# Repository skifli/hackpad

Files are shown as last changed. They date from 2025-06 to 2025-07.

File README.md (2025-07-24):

# hackpad

- [hackpad](#hackpad)
  - [Project Structure](#project-structure)
  - [Journal](#journal)
  - [PCB](#pcb)
    - [Schematic](#schematic)
    - [PCB Design](#pcb-design)
    - [PCB Render](#pcb-render)
  - [CAD](#cad)
  - [BOM](#bom)
  - [Software](#software)

| Cover | Exploded View |
| --- | --- |
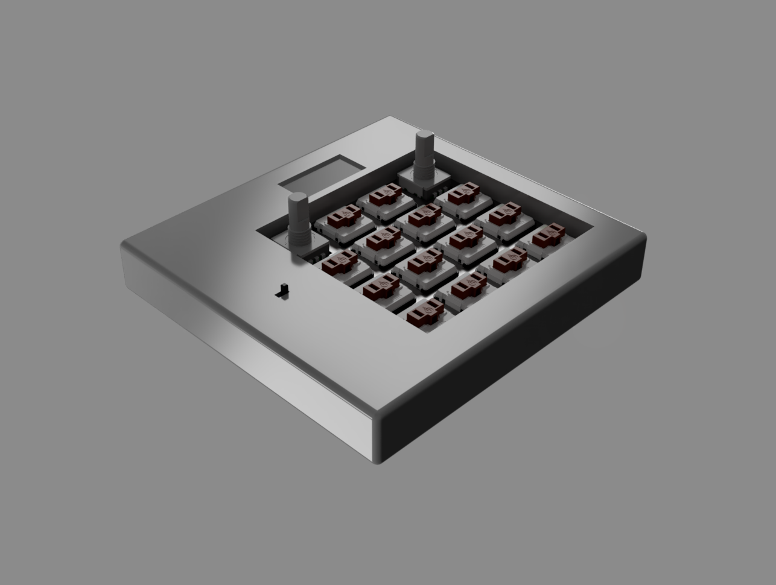
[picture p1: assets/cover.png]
cover photo
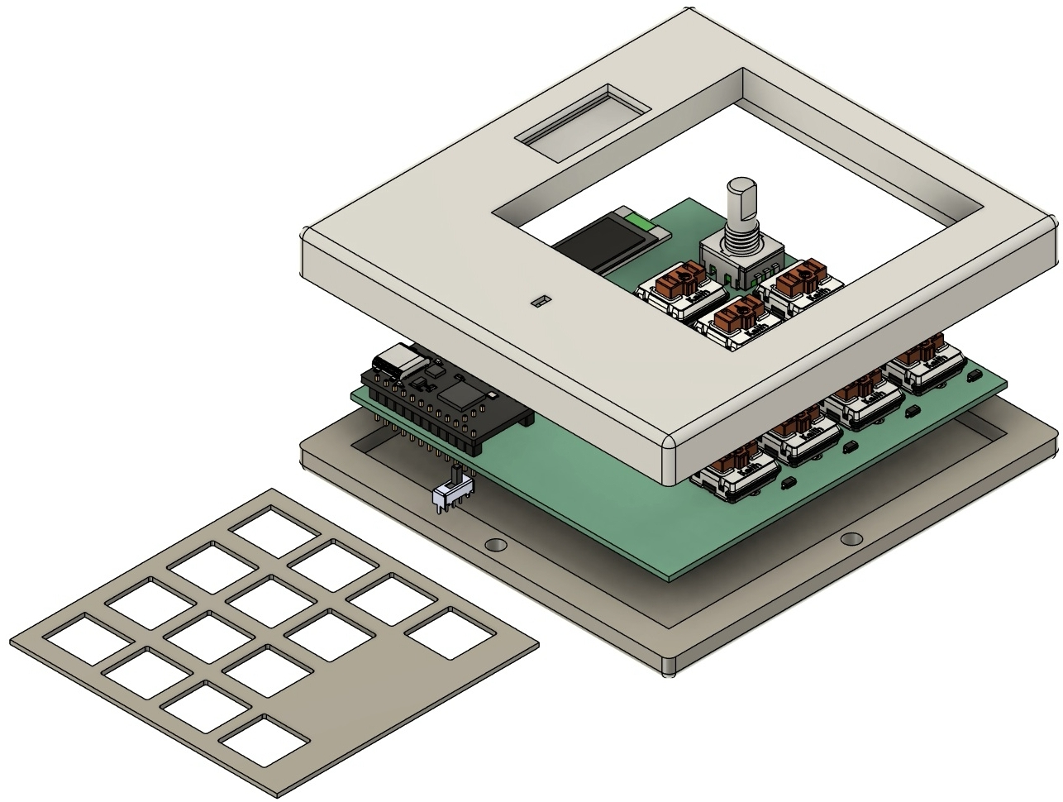
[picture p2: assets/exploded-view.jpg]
exploded view photo
|  |  |

> [!IMPORTANT]\
> Since submission, the BOM price has decreased to $119.89 from above $150 (check [#bom](#bom) for more information).

A fully wireless macropad with 14 Choc v1 Ambient Nocturnal switches, 2 rotary encoders (with a push-button each), and a small screen! The case is in two sections - a top and bottom, and joins together via 8 magnets, half in each side of the case (you can see the magnet holes in the various views).

I made this project because when programming / doing CAD design there are so many different shortcuts I use to make sketches, change orbit types, etc, and these require a lot of clicks. These all could be streamlined a lot more with the use of a macropad - which is why I made this one. I decided to also add a screen so I could easily see which profile I'm on and switch (likely by rotating a rotary encoder while it is held down), and the two rotary encoders to easily control multiple audio streams (mainly YouTube vs. Spotify).

## Project Structure

> [!IMPORTANT]\
> Only includes files / folders relevant to admin that would benefit from explanation.

```
└── 📁hackpad
    └── 📁design
        └── 📁cad
            ├── case_bottom.step
            ├── case_top.step
        └── 📁pcb
            ├── ... # Contains the KiCad directory for the PCB
        └── 📁plate
            ├── ... # Contains the KiCad directory for the plate, which is made from an exported DXF from the Fusion 360 Sketch (plate.dxf)
    ├── JOURNAL.md # The journal of the design process
    └── README.md # This file
```

> [!WARNING]\
> The KiCad plate PCB gives [malformed outline warnings](JOURNAL.md#20072025) and doesn't show correctly in 3D view - no idea why, but when exported with the Fabrication Toolkit and imported into JLCPCB it's totally fine 🗿 (if it works, it works™). 

## Journal

The [journal](JOURNAL.md) contains each day's work, logged, with the aid of images. Total time is at the top and each day has its time logged. There is also a Table of Contents for easy navigation :).

> [!NOTE]\
> Total time spent: **60h**

## PCB

### Schematic

kicad schematic

### PCB Design

kicad pcb design

### PCB Render

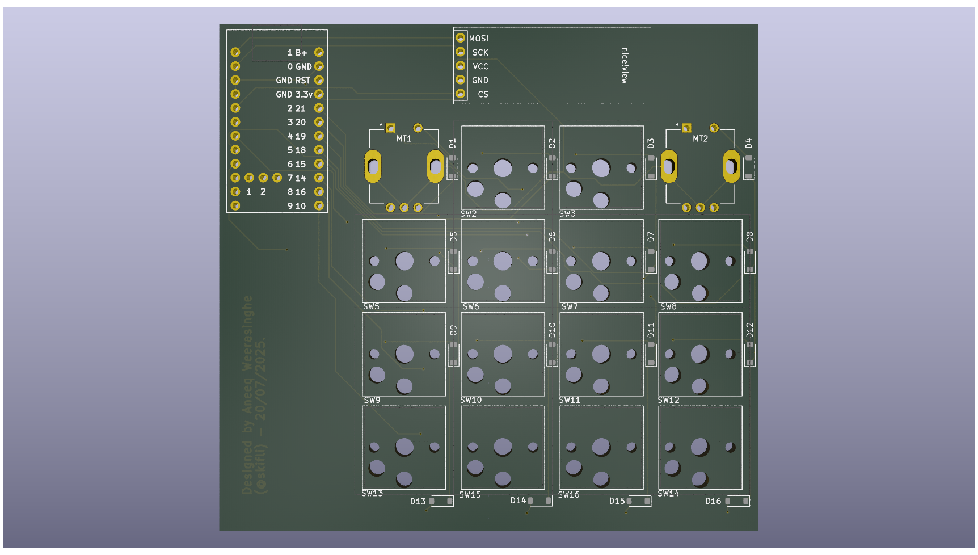
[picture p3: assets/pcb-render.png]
kicad pcb render


## CAD

| Case Top Side View (from the bottom) | Case Bottom Side View (from the top) |
| --- | --- |
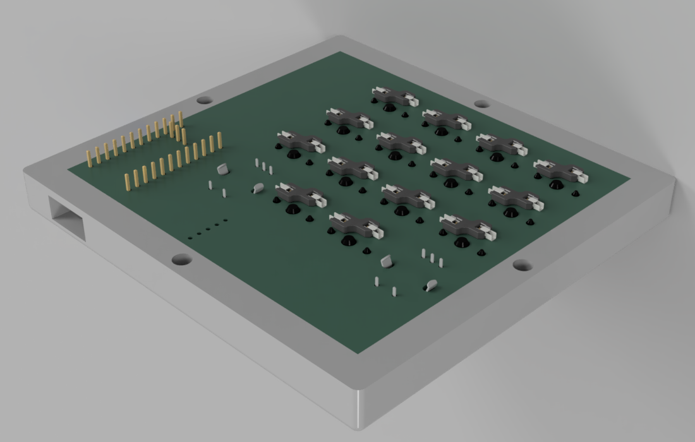
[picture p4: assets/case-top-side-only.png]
case top side only
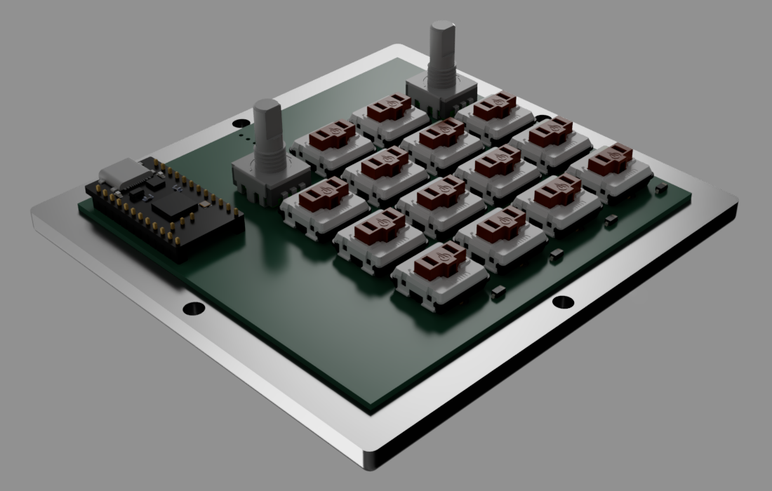
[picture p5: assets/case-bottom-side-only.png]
case bottom side only
|  |  |

| Case Plate | Case USB Port |
| --- | --- |
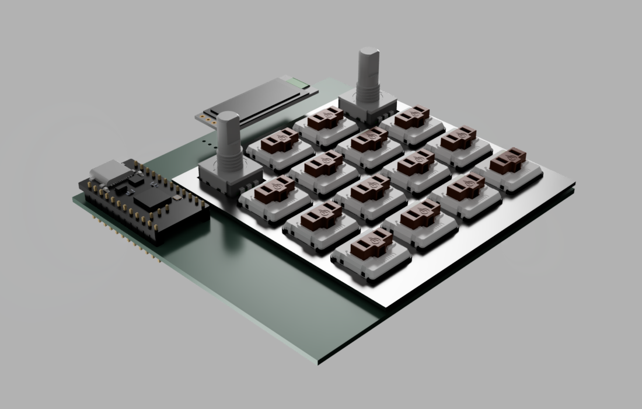
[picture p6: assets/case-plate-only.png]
case plate only
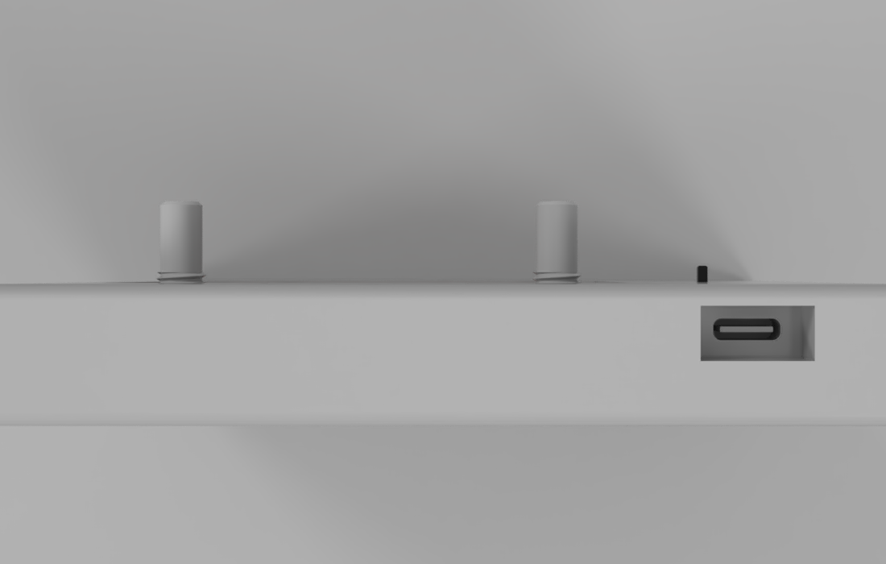
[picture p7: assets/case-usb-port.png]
case usb port
|  |  |

## BOM

> [!TIP]\
> The BOM is split into the different companies from which the components would be bought, with an empty line delimiting them. As well as this, at the end of each section, the total price for that provider, along with the shipping, is provided in the **Price** column. There is also the total price in the aforementioned column on the last row.

> [!NOTE]\
> I found the promo code **KBDNEWS** for Mechboards (a UK-based merchant) 5% off so I included that in the BOM as well to explain the decrease in total price.

<details closed>
<summary>BOM in table format</summary>

| Component | Description | Notes | Qty | Price | Shipping | Provider | Link |
| --- | --- | --- | --- | --- | --- | --- | --- |
| Kailh Choc Hotswap Sockets | V1 (Pack of 10) | | 2 | £6.00 | £1.81 | Mechboards | [Link](https://mechboards.co.uk/products/kailh-choc-hotswap-sockets?variant=40427263754445) |
| DDC Choc (v1) PBT Blank Keycaps - White | White Keycaps / 1u (Pack of 10) | | 1 | £4.50 | – | Mechboards | [Link](https://mechboards.co.uk/products/ddc-choc-pbt-blank-keycaps?variant=47587896426701) |
| DDC Choc (v1) PBT Blank Keycaps - Black | Black Keycaps / 1u (Pack of 10) | | 1 | £4.50 | – | Mechboards | [Link](https://mechboards.co.uk/products/ddc-choc-pbt-blank-keycaps?variant=47405364576461) |
| lowprokb Choc (V1) Ambients Nocturnal | (Pack of 10) | | 2 | £19.00 | – | Mechboards | [Link](https://mechboards.co.uk/products/lowprokb-ambients-silent-linear-nocturnal-choc-v1?variant=47588169908429) |
| KBDNEWS Promo Code | | | – | –£0.94 | – | – | – |
| **Total (Mechboards)** | | | | **£34.11** | *Included* | | |
| nice!nano v2 | | Compatible board | 1 | £2.99 | £2.99 | AliExpress | [Link](https://www.aliexpress.com/item/1005006035267231.html) |
| nice!view | | Compatible screen (without headers) | 1 | £12.69 | – | AliExpress | [Link](https://www.aliexpress.com/item/1005008115497843.html) |
| Header Pins | 1x5 Pins (50 PCS) | Headers for the above screen | 1 | £1.15 | – | AliExpress | [Link](https://www.aliexpress.com/item/4000988113226.html) |
| Tiny Disc Magnet | 4x3mm (100 PCS) | To join the top and bottom of the case | 1 | £4.86 | £2.96 | AliExpress | [Link](https://www.aliexpress.com/item/1005009177139622.html) |
| SMT SOD-123 Diodes | 100 PCS | For the switches | 1 | £1.11 | – | AliExpress | [Link](https://www.aliexpress.com/item/4000685043735.html) |
| Heat Shrink Tubes | | For wiring between switch, battery, nice!nano v2 | 1 | £1.35 | – | AliExpress | [Link](https://www.aliexpress.com/item/1005008146302901.html) |
| JST PH Plug Connector with Wire (M) | MALE 2P 100mm (5 PCS) | For battery wiring | 1 | £0.34 | £1.94 | AliExpress | [Link](https://www.aliexpress.com/item/1005008864177105.html) |
| JST PH Plug Connector with Wire (F) | FEMALE 2P 100mm (5 PCS) | For battery wiring | 1 | £0.49 | £1.94 | AliExpress | [Link](https://www.aliexpress.com/item/1005008864177105.html) |
| Bumper Feet | 5mm x 2mm (100 PCS) | For bottom of the case and PCB | 1 | £1.59 | – | AliExpress | [Link](https://www.aliexpress.com/item/1005004068119765.html) |
| Toggle Switch | K031b004-G3 | To power on/off the system | 1 | £1.94 | – | AliExpress | [Link](https://www.aliexpress.com/item/1005009306874094.html) |
| 3.7V 150mAh | 1 battery | To power the system | 1 | £4.74 | N/A | AliExpress | [Link](https://www.aliexpress.com/item/1005004084377638.html) |
| Rotary Encoder w/ Push Button | 5 PCS | | 1 | £1.08 | – | AliExpress | [Link](https://www.aliexpress.com/item/1005005983134515.html) |
| **Total (AliExpress)** | | | | **£42.35** | *Included* | | |
| Plate & PCB | | | | £5.94 | £6.11 | JLCPCB | N/A |
| **Total (JLCPCB)** | | | | **£12.05** | *Included* | | |
| **TOTAL** | | | | **£88.51** | *Included* | | |  |

</details>

> [!IMPORTANT]\
> Please disregard a lot of what is in the below text. After someone in the Slack (@Toby), introduced me to the world of AliExpress, I completely redid the BOM. It is now $119.89 (yes that is USD lol), so way under the limit. Thanks a lot dude :).

The BOM can be found in [`/bom.csv`](bom.csv). Since this is my first ever hardware project, I decided to go for some products that were easier to find footprints / symbols in KiCad for. With hindsight, spending the amount of money I now have to on a nice! nano v2 or nice!view (which I landed on because I chose the nice! nano v2) isn't really necessary. So, in future projects I'll choose other, cheaper components - but for this one I've already designed the PCB etc, and was very new to this whole world of design, and so decided to go with components that I was more confident with.

The Seeed Studio XIAO RP2040 didn't have enough GPIO anyway since I needed a 4x4 key matrix (so 8 pins), 4 other GPIO for the 2 rotary encoders, and the screen pins. Now, unfortunately this does mean the price is way over $150. This is in part because I also forgot Hackclub operates in USD and so was sure I would be in price range until 2 days ago, at which point I had a heart attack 😭. I'll try to cover the rest myself... not really sure how that'll go because I need to buy solder and other stuff since this is my first hardware project (which is already a lot of money), but we'll see... I'm not sure if Hackclub has a thing with JLCPCB for cheaper PCBs but if so that would reduce the total cost, although it might still be just over $150.

## Software

Will be _mostly_ added once the physical components are received and assembled, as I don't want to start writing code and then find out it doesn't work because I accidentally used libraries for different components, or something similar to that.

I have added some stuff in the [`/software`](software) directory though.

---
<sub>Thanks to [Hackclub](https://hackclub.com) for such an amazing opportunity - this project was made by [@skifli](https://github.com/skifli) with 🩷, under the [MIT License](LICENSE).</sub>

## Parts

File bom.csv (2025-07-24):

Component | Description | Notes | Quantity | Price | Shipping | Provider | Link
Kailh Choc Hotswap Sockets | V1 (Pack of 10) |  | 2 | £6.00 | £1.81 | Mechboards | https://mechboards.co.uk/products/kailh-choc-hotswap-sockets?variant=40427263754445
DDC Choc (v1) PBT Blank Keycaps - White | White Keycaps / 1u (Pack of 10) |  | 1 | £4.50 |  |  | https://mechboards.co.uk/products/ddc-choc-pbt-blank-keycaps?variant=47587896426701
DDC Choc (v1) PBT Blank Keycaps - Black | Black Keycaps / 1u (Pack of 10) |  | 1 | £4.50 |  |  | https://mechboards.co.uk/products/ddc-choc-pbt-blank-keycaps?variant=47405364576461
lowprokb Choc (V1) Ambients Nocturnal | (Pack of 10) |  | 2 | £19.00 |  |  | https://mechboards.co.uk/products/lowprokb-ambients-silent-linear-nocturnal-choc-v1?variant=47588169908429
KBDNEWS Promo Code |  |  |  | -5%
Total (Mechboards) |  |  |  | £34.11 | Included on the left
nice!nano v2 |  | Compatible board | 1 | £2.99 | £2.99 (Base) | AliExpress | https://www.aliexpress.com/item/1005006035267231.html?mp=1
nice!view |  | Compatible screen (without headers) | 1 | £12.69 |  |  | https://www.aliexpress.com/item/1005008115497843.html?mp=1
Header Pins | 1x5 Pins (50 PCS) | Headers for the above screen since it doesn't come with them | 1 | £1.15 |  |  | https://www.aliexpress.com/item/4000988113226.html?mp=1
Tiny Disc Magnet | 4x3mm (100 PCS) | To join the top and bottom of the case | 1 | £4.86 | £2.96 |  | https://www.aliexpress.com/item/1005009177139622.html?mp=1
SMT SOD-123 Diodes | 100 PCS | For the switches | 1 | £1.11 |  |  | https://www.aliexpress.com/item/4000685043735.html?mp=1
Heat Shrink Tubes |  | Because I'm going to some wires to join the switch inbetween the nice! nano v2 and the battery | 1 | £1.35 |  |  | https://www.aliexpress.com/item/1005008146302901.html?mp=1
JST PH Plug Connector with Wire | MALE 2P 100mm (5 PCS) | Same as above | 1 | £0.34 | £1.94 |  | https://www.aliexpress.com/item/1005008864177105.html?mp=1
JST PH Plug Connector with Wire | FEMALE 2P 100mm (5 PCS) | Same as above | 1 | £0.49 | £1.94 |  | https://www.aliexpress.com/item/1005008864177105.html?mp=1
Bumper Feet | 5mm x 2mm (100PCS0 | For the bottom of the case and the PCB | 1 | £1.59 |  |  | https://www.aliexpress.com/item/1005004068119765.html?mp=1
Toggle Switch | K031b004-G3 | To power on / off the system | 1 | £1.94 |  |  | https://www.aliexpress.com/item/1005009306874094.html?mp=1
3.7V 150mAh | 1 battery | To power the system | 1 | £4.74 | N/A |  | https://www.aliexpress.com/item/1005004084377638.html?scm_id=1007.40050.354490.0&scm-url=1007.40050.354490.0
Rotary Encoder w/ Push Button | 5 PCS |  | 1 | £1.08 |  |  | https://www.aliexpress.com/item/1005005983134515.html?mp=1
Total (AliExpress) |  |  |  | £42.35 | Included on the left
Plate & PCB |  |  |  | £5.94 | £6.11 | JLCPCB | N/A
Total (JLCPCB) |  |  |  | £12.05 | Included on the left
TOTAL |  |  |  | £88.51 | Included on the left

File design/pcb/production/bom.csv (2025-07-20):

Designator | Footprint | Quantity | Value | LCSC Part #
D1, D10, D11, D12, D13, D14, D15, D16, D2, D3, D4, D5, D6, D7, D8, D9 | D_SOD-123 | 16 | Diode
DISPLAY1 | nice_view | 1 | nice!view
MT1, MT2 | XDCR_PEC11R-4215F-S0024 | 2 | PEC11R-4215F-S0024
SW10, SW11, SW12, SW13, SW14, SW15, SW16, SW2, SW3, SW5, SW6, SW7, SW8, SW9 | Hotswap_Choc_V1_1.00u | 14 | Switch
U1 | Nice_Nano_V2 | 1 | Nice_Nano_V2

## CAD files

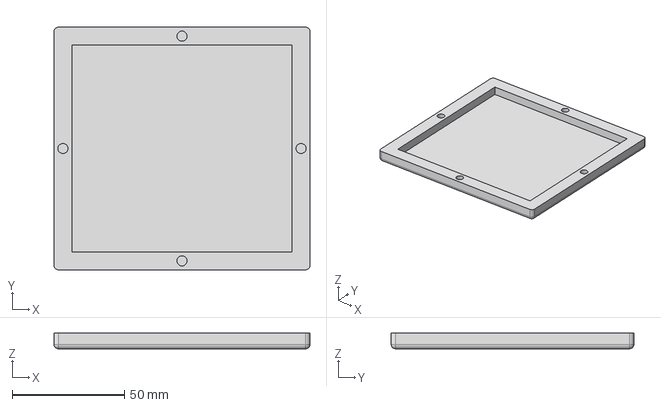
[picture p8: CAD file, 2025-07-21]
design/case/case_bottom.step
114.2 x 108.3 x 7.00 mm

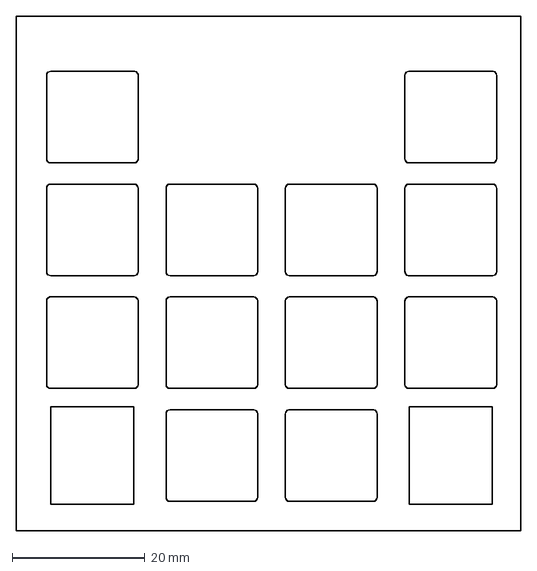
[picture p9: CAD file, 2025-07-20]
design/plate/plate.dxf
76.1 x 77.6 mm

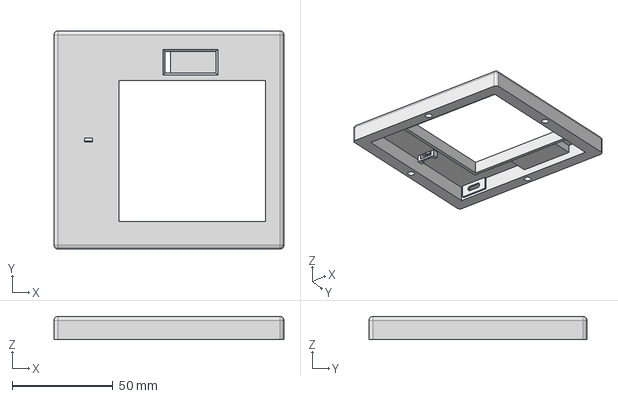
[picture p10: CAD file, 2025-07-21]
design/case/case_top.step
114.2 x 108.3 x 11.5 mm

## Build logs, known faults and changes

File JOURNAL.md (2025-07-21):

---
title: "Hackpad"
author: "skifli"
description: "A custom macropad with rotary encoders, a screen, and a lotta keys"
created_at: "2025-06-27"
---

# Journal

- [Journal](#journal)
  - [27/06/2025](#27062025)
  - [28/06/2025](#28062025)
  - [29/06/2025](#29062025)
    - [Mechboards](#mechboards)
    - [PiHut](#pihut)
  - [30/06/2025](#30062025)
  - [01/07/2025](#01072025)
  - [02/07/2025](#02072025)
  - [03/07/2025](#03072025)
  - [04/07/2025](#04072025)
  - [05/07/2025](#05072025)
  - [06/07/2025](#06072025)
  - [08/07/2025](#08072025)
  - [09/07/2025](#09072025)
  - [17/07/2025](#17072025)
  - [20/07/2025](#20072025)
  - [21/07/2025](#21072025)

> [!NOTE]\
> Total time spent: **60h**

## 27/06/2025

I did some research on different microcontrollers I could use. I first landed on the [Elite C](https://mechboards.co.uk/products/elite-c-v4), but every single site I looked on was out of stock ;-;, so maybe not a good choice. Eventually I decided on the Raspberry Pi Pico compared to the XIAO RP2040 in the Hackpad tutorial, because its got a lotta more GPIO, and even though its bigger for me thats fine (I think, so far). I might integrate a Micro USB to USB C adapter though, I REALLY want USB C lol.

Found this [Github Repo](https://github.com/ncarandini/KiCad-RP-Pico/) with the 3D footprint etc of the Raspberry Pi Pico for KiCad. Installed it and set it up.

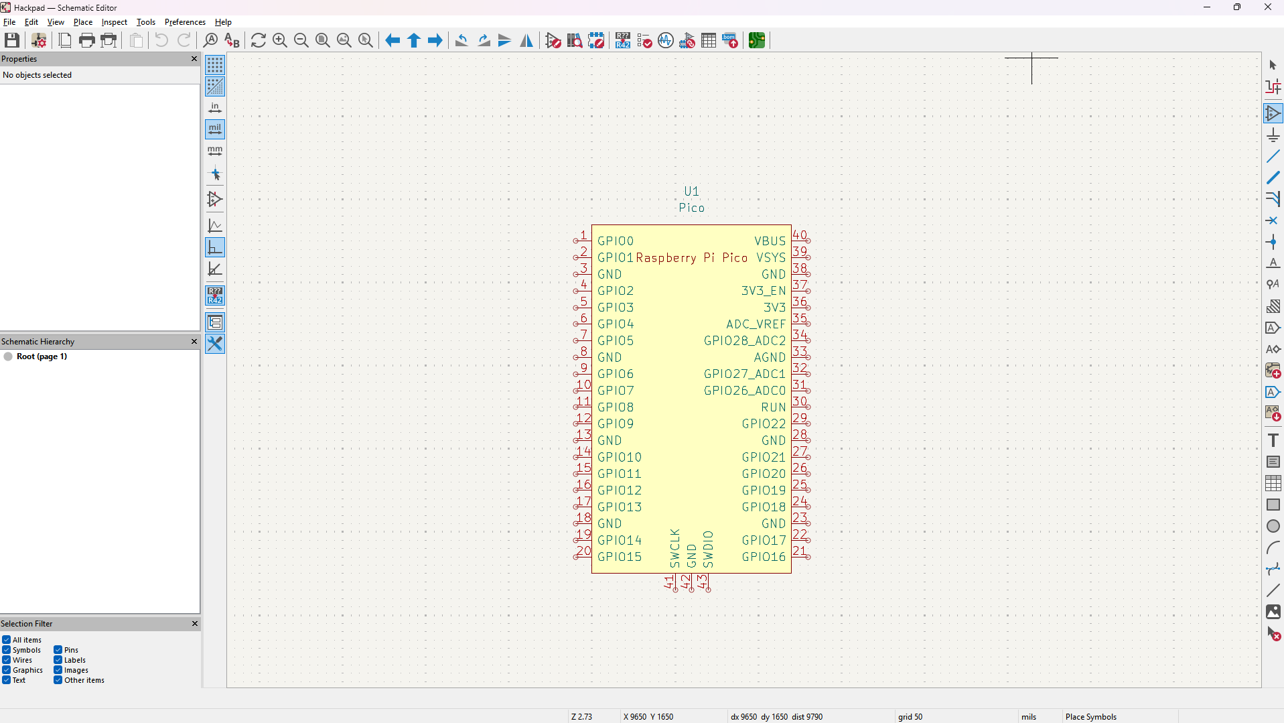
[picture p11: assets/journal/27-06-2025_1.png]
basic board image


> [!NOTE]\
> Total time spent: **1h**

## 28/06/2025

Going to use the SSD1306 128x64 screen:

* Purchase Link: https://thepihut.com/products/0-96-oled-display-module-128x64
* KiCad Symbol: https://github.com/pforrmi/KiCad-SSD1306-128x64 (Not in the official KiCad Symbol Library)
* KiCad Footprint: https://kicad.github.io/footprints/Display
* KiCad 3D Model: https://kicad.github.io/packages3d/Display

Ok so after discovering https://github.com/joe-scotto/scottokeebs/tree/main/Extras/ScottoKicad I've just switched to using that because it has symbols, footprints, and 3D models of a bunch of different OLEDs and switches which is nice. This OLED is cheaper and fits the footprint / 3D model: https://thepihut.com/products/0-96-oled-display-module-128x64.

* Rotary Encoder: https://mechboards.co.uk/products/rotary-encoder?variant=40330076651725
* Keycaps: https://mechboards.co.uk/products/ddc-choc-pbt-blank-keycaps?variant=47587896426701 and https://mechboards.co.uk/products/ddc-choc-pbt-blank-keycaps?variant=47405364576461
* Switches: https://mechboards.co.uk/products/lowprokb-ambients-silent-linear-nocturnal-choc-v1?variant=47588169908429

Back to seed XIAO because now doing 10 keys instead of 20.

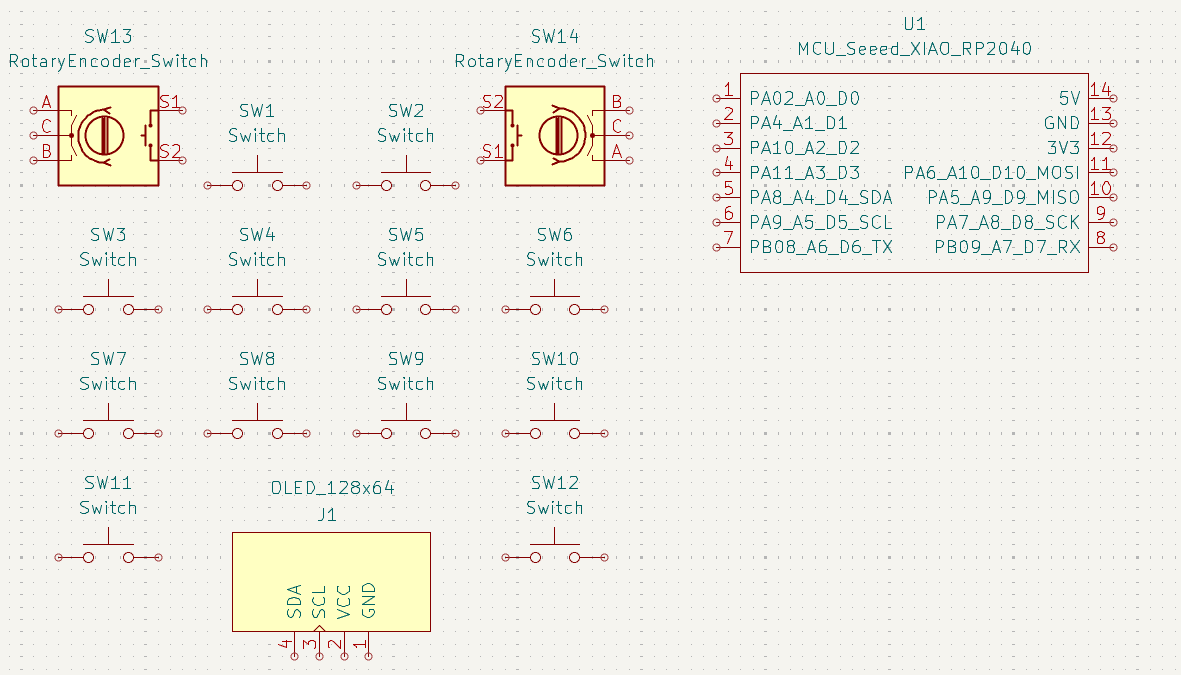
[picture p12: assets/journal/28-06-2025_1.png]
schematic image with no wires


Really useful video on a key matrix that helped me visualise it: https://www.youtube.com/watch?v=7LyziNdFlew. Back to Raspberry Pi Pico because the Seed XIAO RP 2040 STILL needs 1 more GPIO for me to use it ;-;.

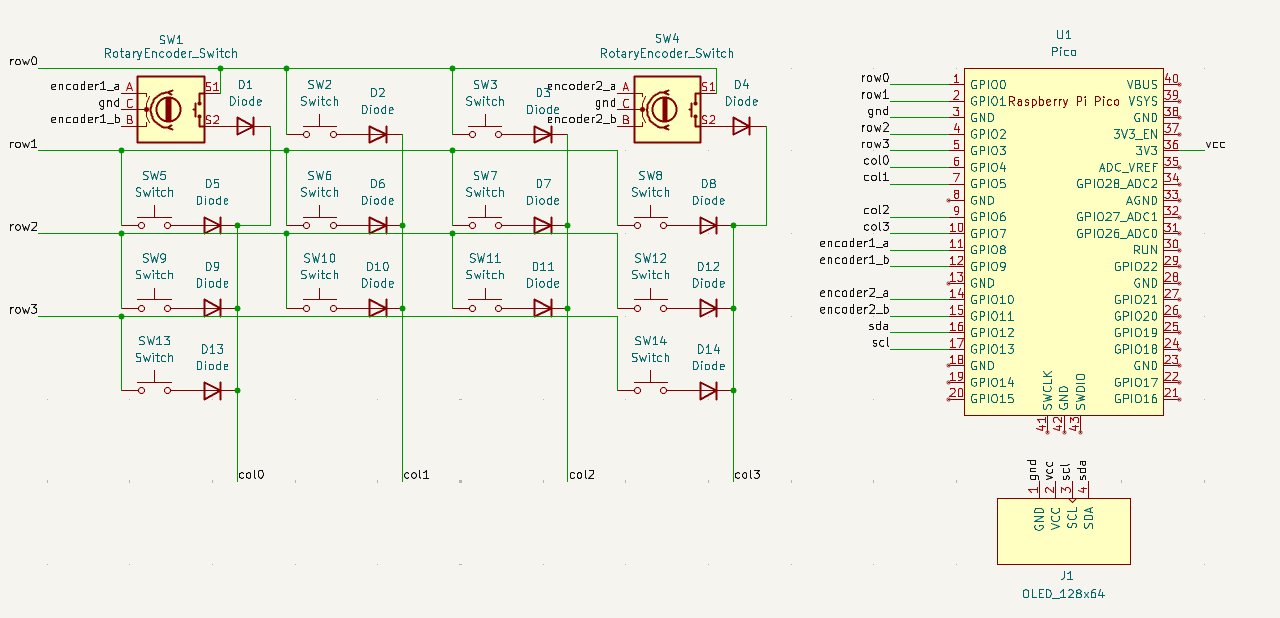
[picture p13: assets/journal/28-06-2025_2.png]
schematic image with keyboard matrix


> [!NOTE]\
> Total time spent: **3h**

## 29/06/2025

Finalised parts after a lot of searching (nice!nano v2 for Bluetooth communication):

### Mechboards
* 2x [10 lowprokb Choc (V1) Ambients Nocturnal](https://mechboards.co.uk/products/lowprokb-ambients-silent-linear-nocturnal-choc-v1?variant=47588169908429).
* 1x [10 DDC Choc (v1) PBT Blank Keycaps (White Keycaps / 1u)](https://mechboards.co.uk/products/ddc-choc-pbt-blank-keycaps?variant=47587896426701).
* 1x [10 DDC Choc (v1) PBT Blank Keycaps (Black Keycaps / 1u)](https://mechboards.co.uk/products/ddc-choc-pbt-blank-keycaps?variant=47405364576461).
* 2x [10 Choc V1 Hotwsap Sockets](https://mechboards.co.uk/products/kailh-choc-hotswap-sockets?variant=40427263754445).
* 1x [50 Throughole Diodes](https://mechboards.co.uk/products/throughhole-diodes?variant=41360419193037).
* 1x [nice! nano v2](https://mechboards.co.uk/products/nice-nano-v2?variant=40330076782797).

### PiHut
* 1x [1200mAh 3.7V LiPo Battery](https://thepihut.com/products/1200mah-3-7v-lipo-battery?variant=42143258214595). [CHANGED LATER TO WAY SMALLER ONE].
* 1x [Adafruit Micro-Lipo Charger for LiPoly Batt with USB Type C Jack](https://thepihut.com/products/adafruit-micro-lipo-charger-for-lipoly-batt-with-usb-type-c-jack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). [REALISED LATER I DON'T NEED]
* 1x [Breadboard-friendly SPDT Slide Switch](https://thepihut.com/products/breadboard-friendly-spdt-slide-switch?variant=27740501649).
* 1x [20 Tactile Button switch (6mm)](https://thepihut.com/products/tactile-button-switch-6mm-x-20-pack?variant=27740416657).
* 2x [Rotary Encoder + Extras](https://thepihut.com/products/rotary-encoder-extras?variant=27740417681).

Found the [PCB files](https://github.com/adafruit/Adafruit-MicroLipo-PCB/tree/master) for the Adafruit Micro-Lipo charger but they weren' for KiCad (`.brd` / `.sch`) file type. After converting it (which took a LOT of time ;-;) I realised they were actual PCB files for the board, so I had to create my own schematic of how I would interface with it, not the board itself.

Custom symbol based on the schematic of the board:
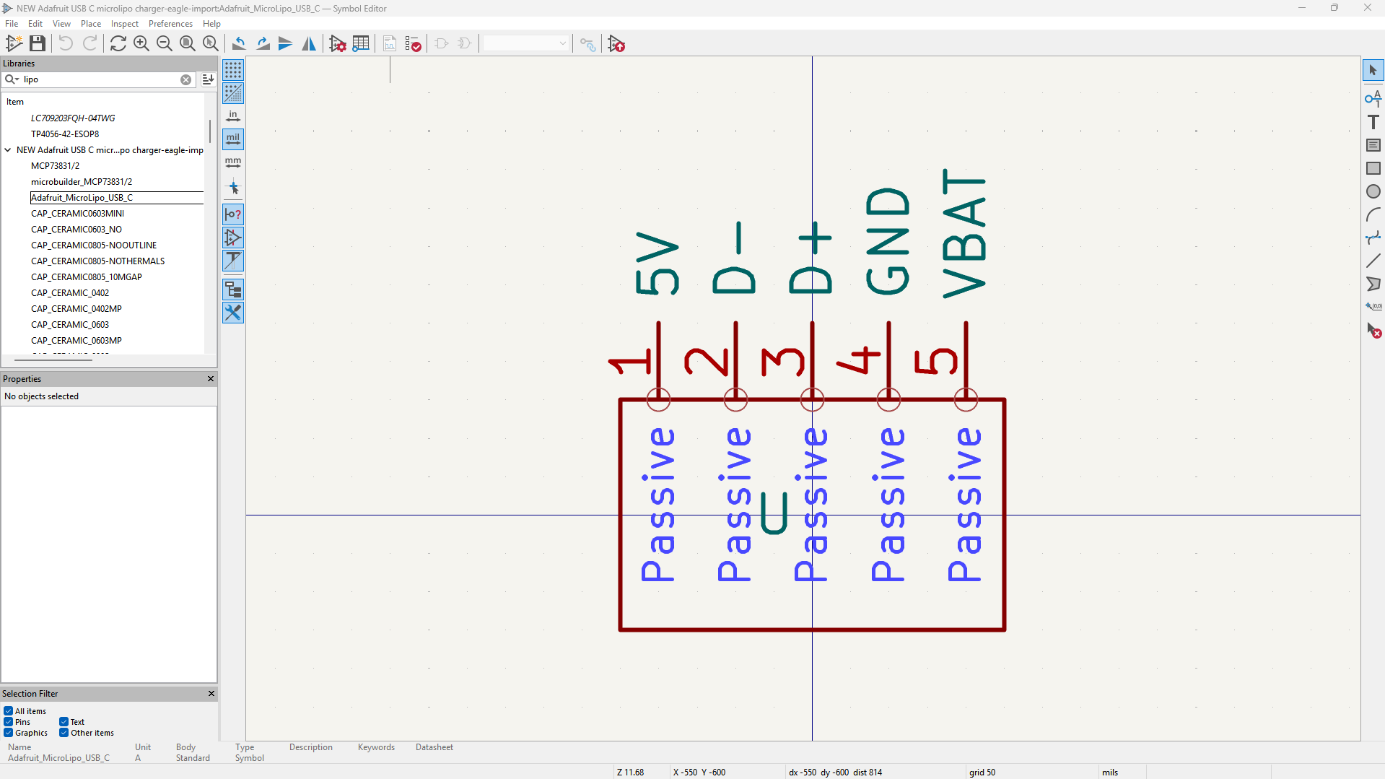
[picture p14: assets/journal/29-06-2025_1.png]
custom symbol of the adafruit micro lipo charger


Some silkscreen stuff got messed up but I still managed to get the general dimensions of the PCB into a footprint:
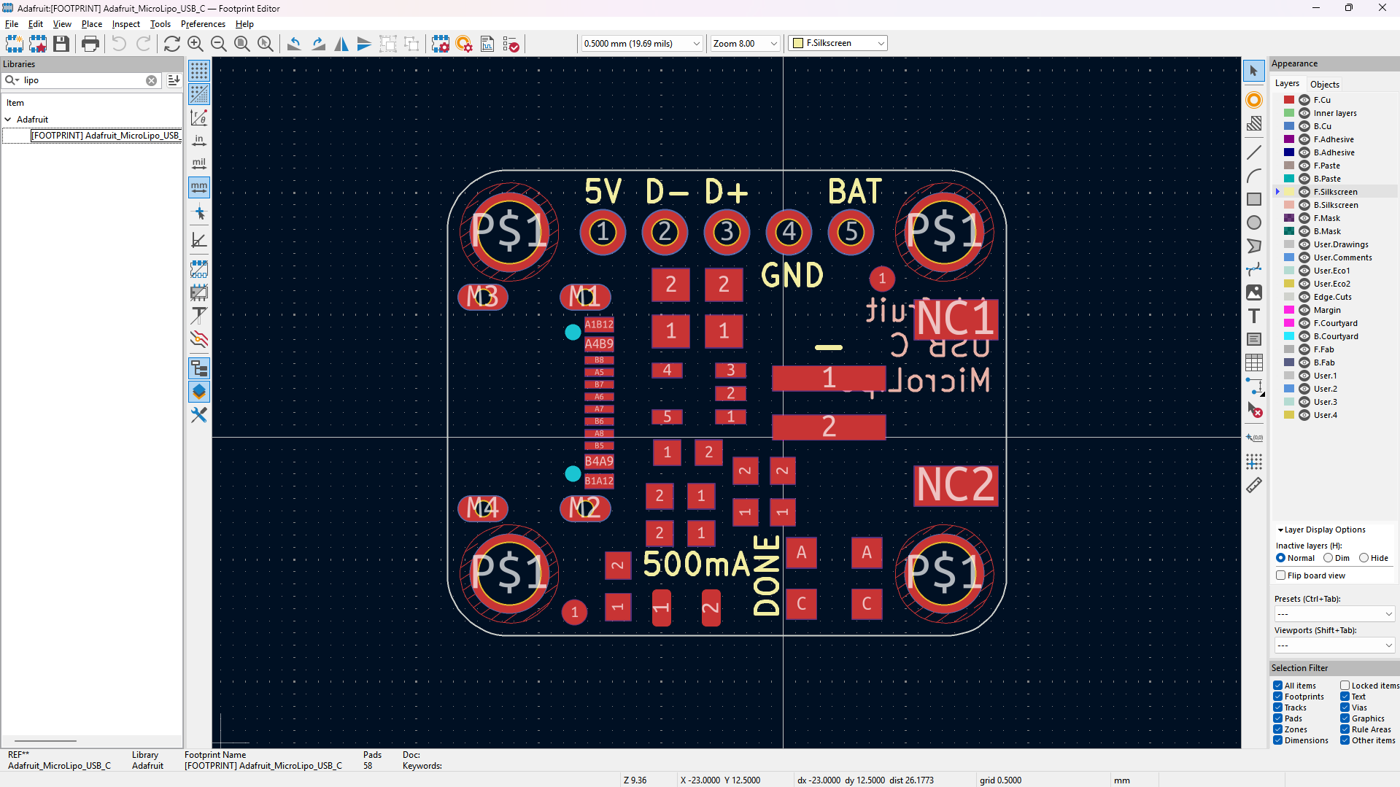
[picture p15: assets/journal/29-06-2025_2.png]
custom-ish pcb of the adafruit micri lipo charger


Schematic by the end of the day - I switched a bunch of the symbols to specific ones for my parts, etc:

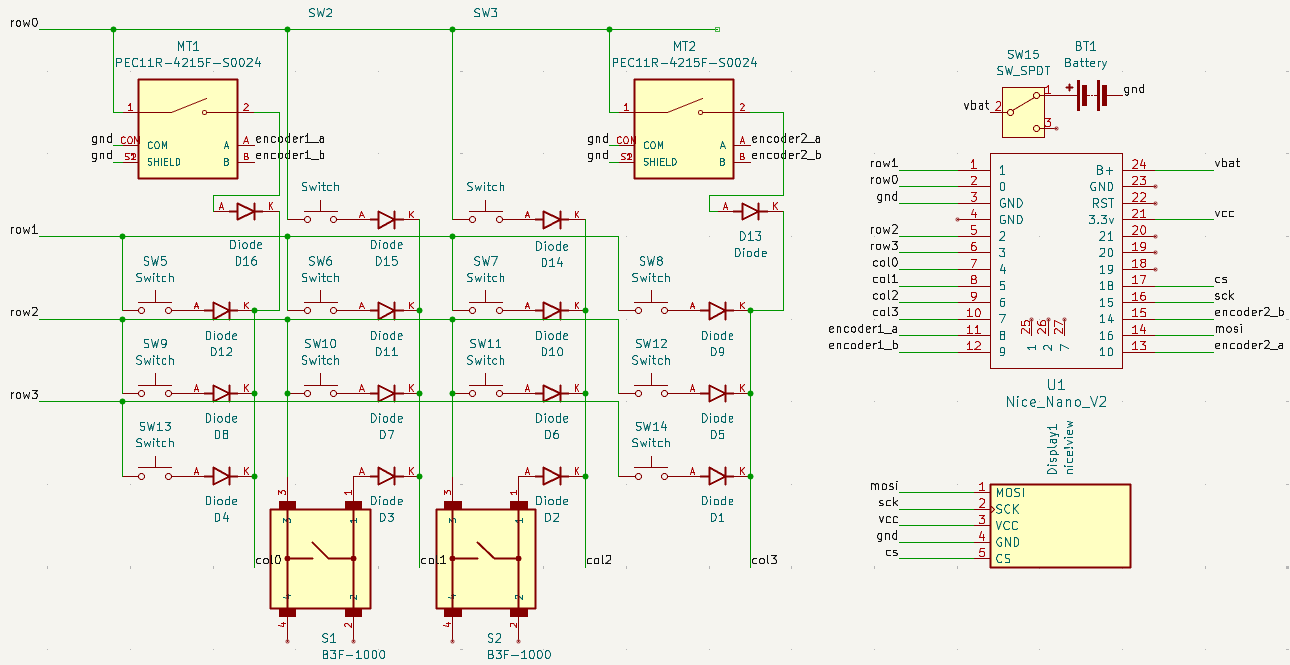
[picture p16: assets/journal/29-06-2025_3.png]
full schematic at the end of 29/06/2025


> [!NOTE]\
> Total time spent: **6h**

## 30/06/2025

Created a custom symbol for the 1200mAh 3.7V LiPo Battery.
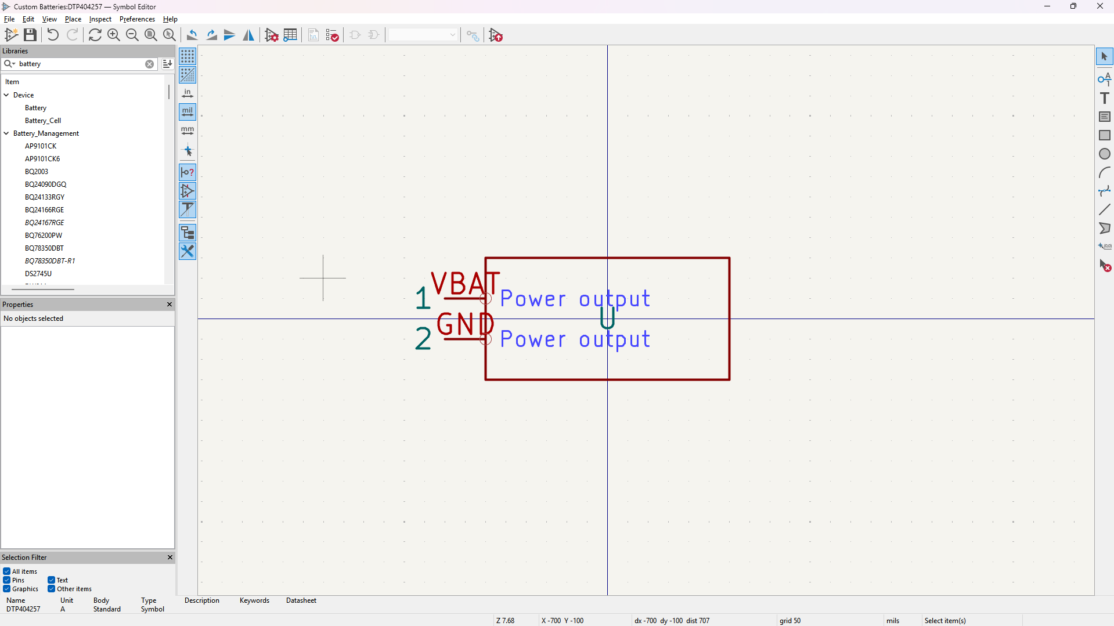
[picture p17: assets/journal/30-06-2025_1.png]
custom symbol for the battery


Nevermind I found the KiCad symbol and footprint for the connectors used in the battery - https://www.snapeda.com/parts/PHR-2/JST/view-part/, so I'm going to use the symbol from there. 

Made a simple footprint for the Battery, without pins as those plug into the Adafruit Micro-Lipo Charger.

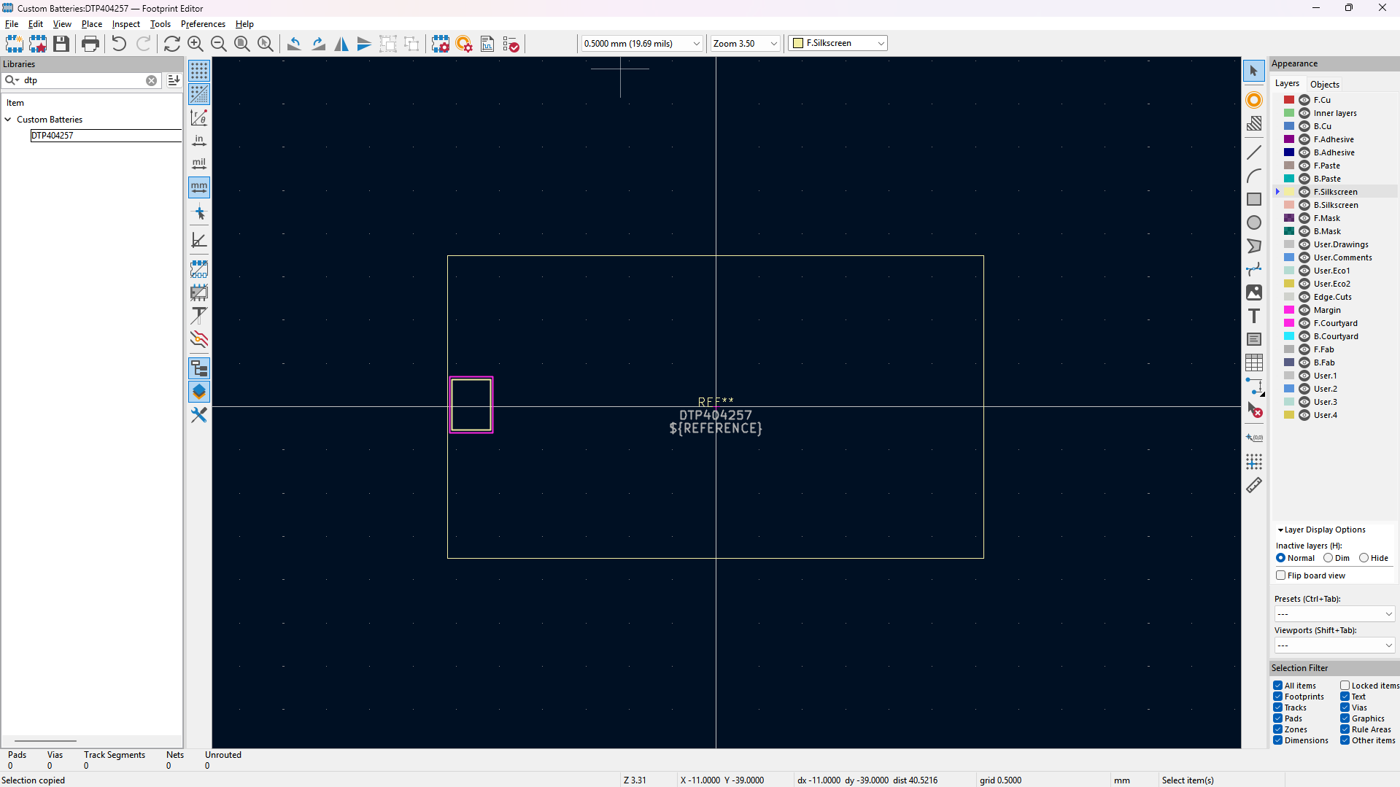
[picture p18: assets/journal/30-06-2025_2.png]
custom footprint for the battery


I've now realised the Battery stuff has no use because I should interface with the LiPo charger instead...

Found the [3D model of the switch from PiHut](https://www.snapeda.com/parts/SS-12D01-G4ENS/C&K/view-part/), but it doesn't have a symbol or footprint (time to make it :sob:). About 20 minutes later - nevermind I found the symbol and footprint on [JLCPCB](https://jlcpcb.com/partdetail/DEALON-SS_12D01G4/C2998804), and through the linked EasyEDA stuff I exported it and imported and linked 'em in KiCad!

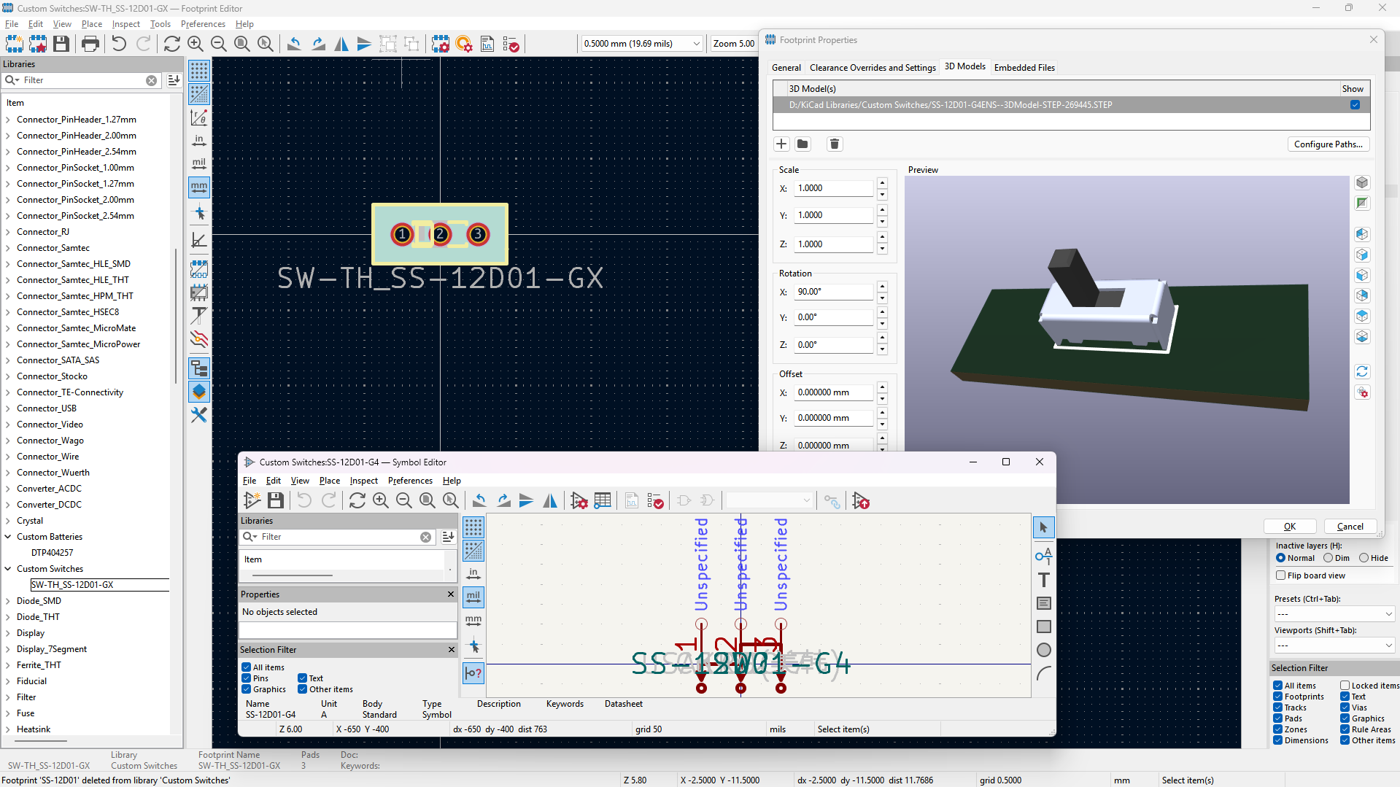
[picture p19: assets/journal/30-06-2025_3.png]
the 3d model of the switch from PiHut in KiCad linked to its footprint


> How do you charge the nice!nano?#
> The nice!nano has a Li-Po charger built in that uses the USB-C port to charge the Li-Po at a rate of 100mA.

Oh great. WHY DID I MISS THIS :sob:. I don't need the Adafruit charger now ;-;.

How to do a switch with the JST thingy:
* https://www.youtube.com/watch?v=K1CbrNh6a1s
* https://learn.adafruit.com/on-slash-off-switches/overview

The battery will connect with the JST PH 2-Pin Cable - Male Header, this makes it longer, and this will be unpluggable and used for all batteries. This then will be cut and soldered with the switch (so I will buy the JST-PH 2-pin Jumper Cable - 100mm long for extra wire in case I make some mistakes, and also Heat Shrink Pack to insulate around the soldered joints). Then the black end goes to GND (SAME AS OTHERS), red to BAT+ which is BATTERY (top right).

Schematic by the end of the day:
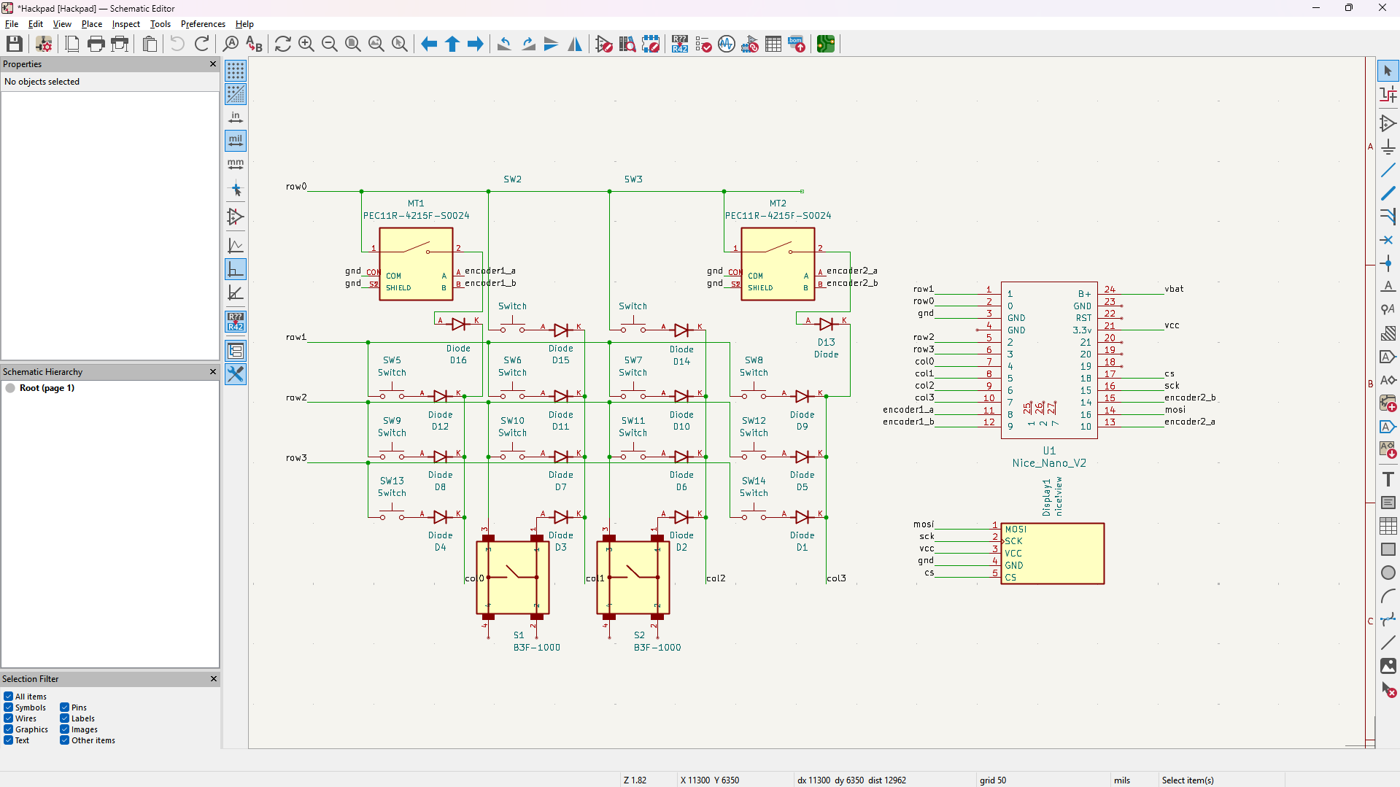
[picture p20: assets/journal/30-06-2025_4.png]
schematic at the end of 30/06/2025


> [!NOTE]\
> Total time spent: **5h**

## 01/07/2025

Swtiched to this battery https://thepihut.com/products/150mah-3-7v-lipo-battery - other one is overkill and this is smaller lol.

I now realised theres a difference between high and low frequency pins, so after a bit of general schematic cleanup and reordering of GPIOs, I finished with this (now the whole key matrix is on low freq so there isn't a mix of high / low freq GPIO):

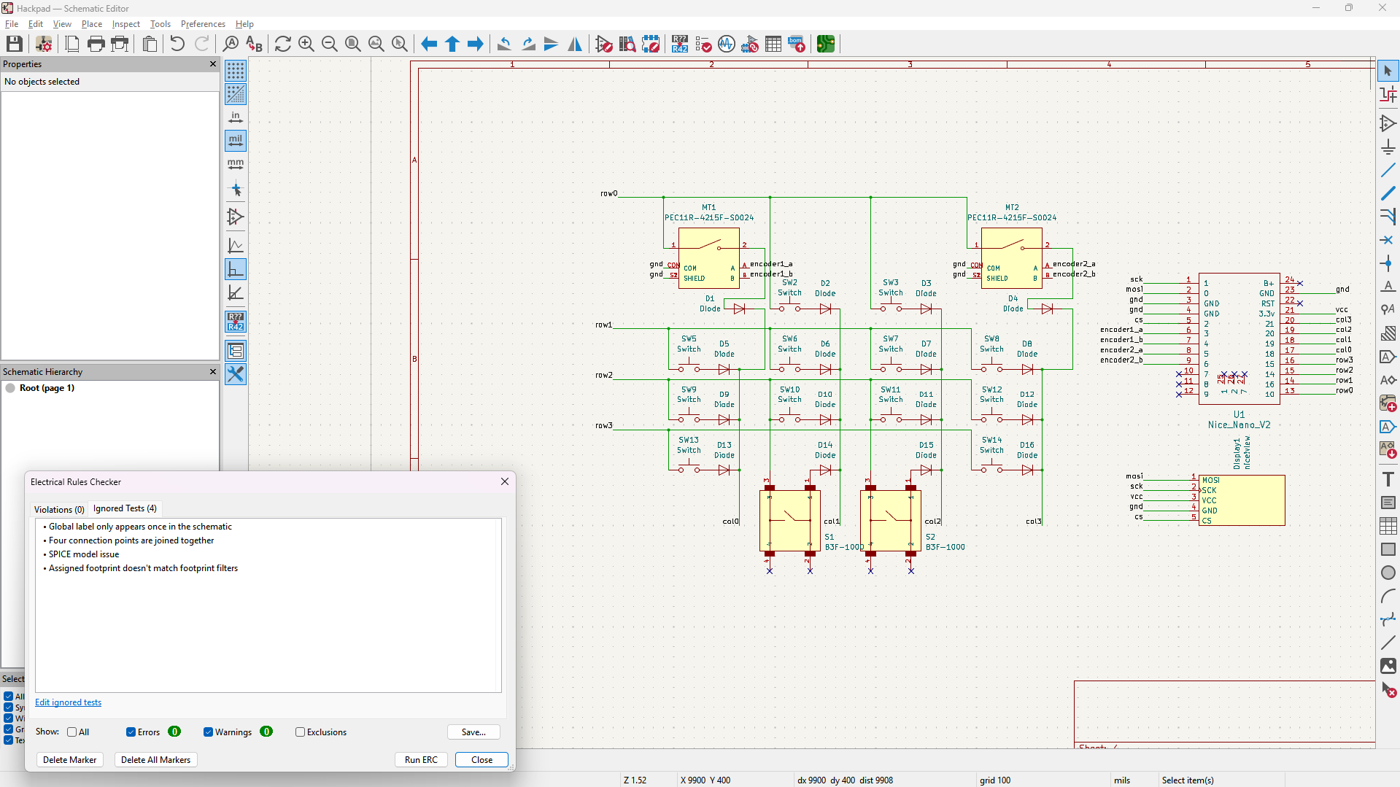
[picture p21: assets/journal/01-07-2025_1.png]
fixed schematic taking into account low / high frequency pins


Great helping source / documentation: https://docs.splitkb.com/product-guides/aurora-series/build-guide/diodes.

> [!NOTE]\
> Total time spent: **4h**

## 02/07/2025

Sorry for like no journalling today lol but I did a LOT on the PCB design (except for routing) for now (will probably change the bottom buttons later).

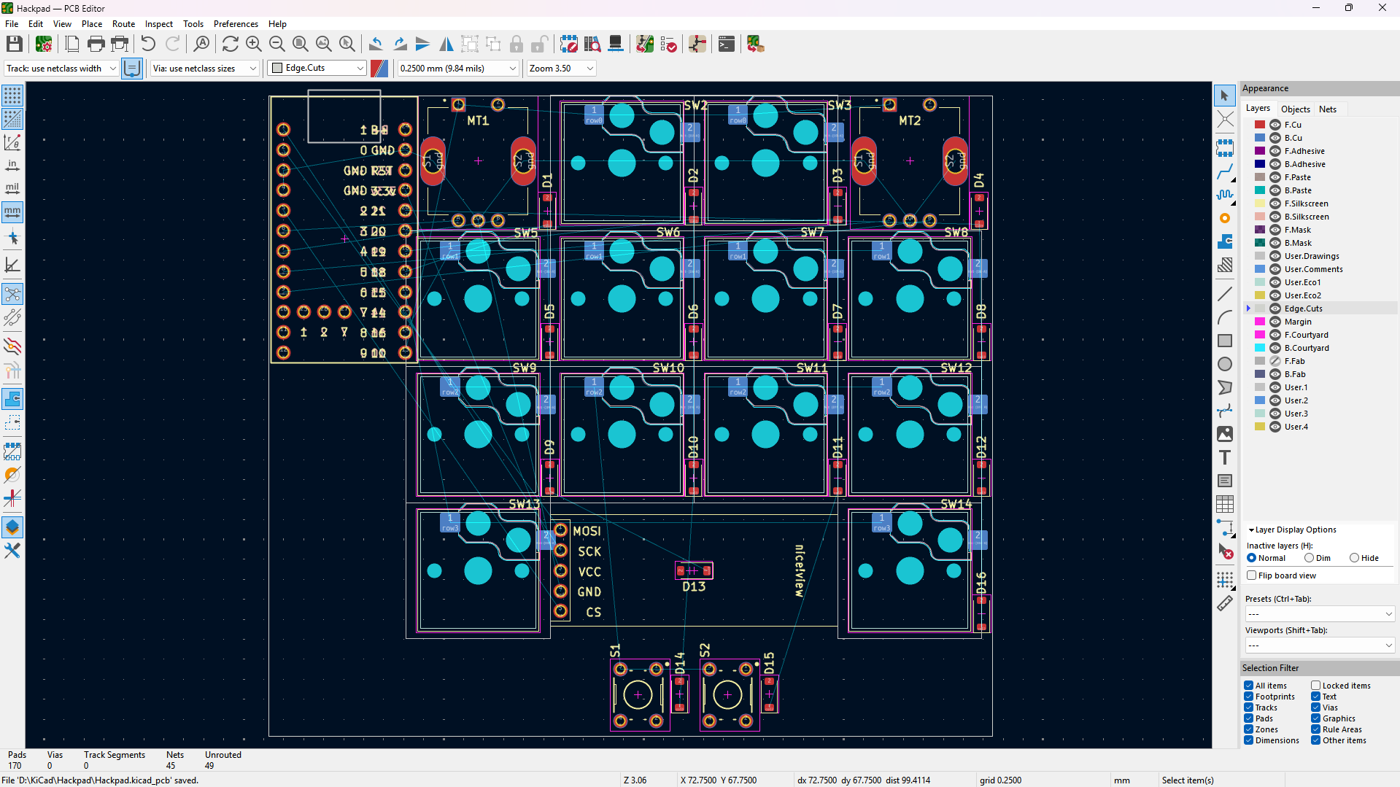
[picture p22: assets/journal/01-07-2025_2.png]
PCB nearly finished


Slight problem here:

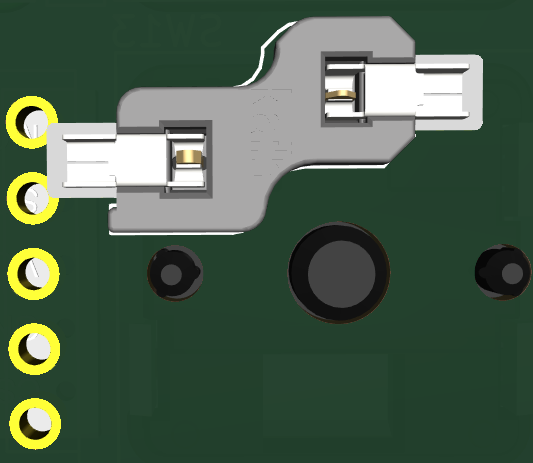
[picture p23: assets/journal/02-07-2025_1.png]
Problem with the PCB with pads for diodes touching display pin holes


Fixed here:

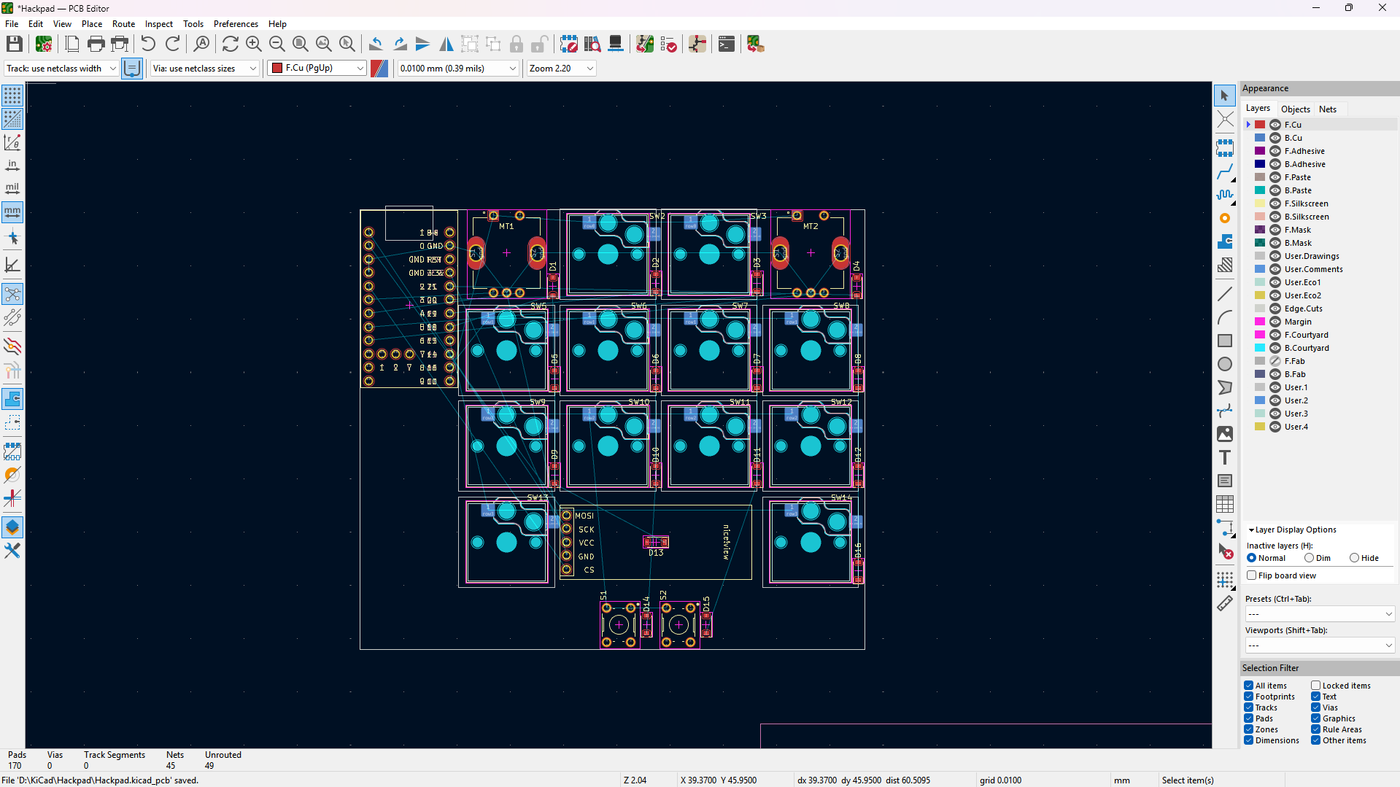
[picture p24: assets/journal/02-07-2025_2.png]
Fix of the above problem


Switches were upside down ;-;. So the above was useless... (as when the RIGHT way up they did NOT collide).

So I fixed that.

> [!NOTE]\
> Total time spent: **5h**

## 03/07/2025

Spent most of today getting some more 3D models into KiCad and reordering some stuff like diodes etc:

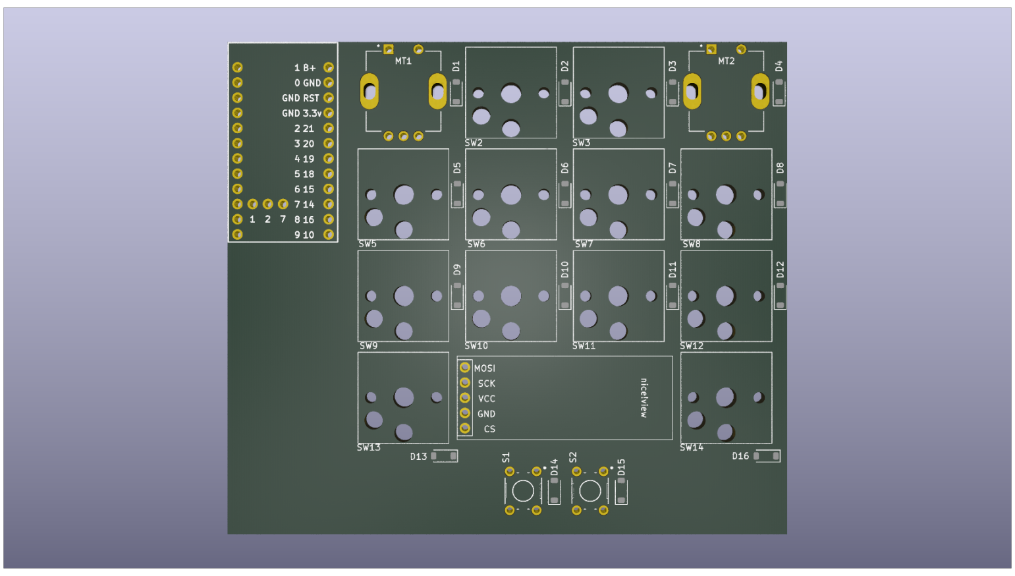
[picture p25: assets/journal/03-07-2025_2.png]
pcb by end of day


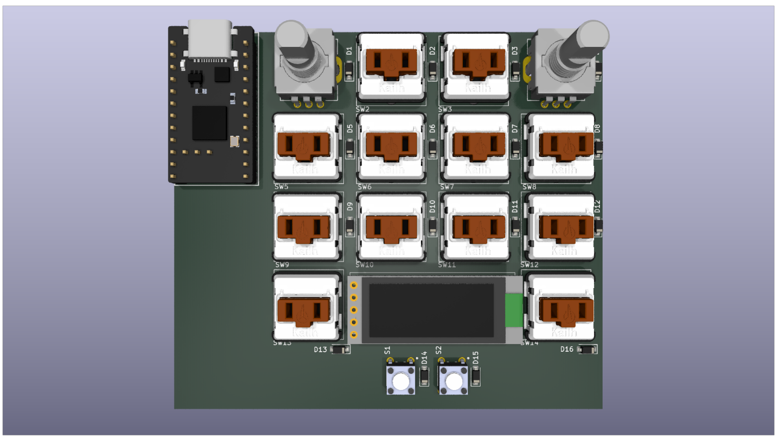
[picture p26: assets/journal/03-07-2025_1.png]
pcb with 3d models by end of day


> [!NOTE]\
> Total time spent: **2h**

## 04/07/2025

Finished PCB layout, now just need to route it.

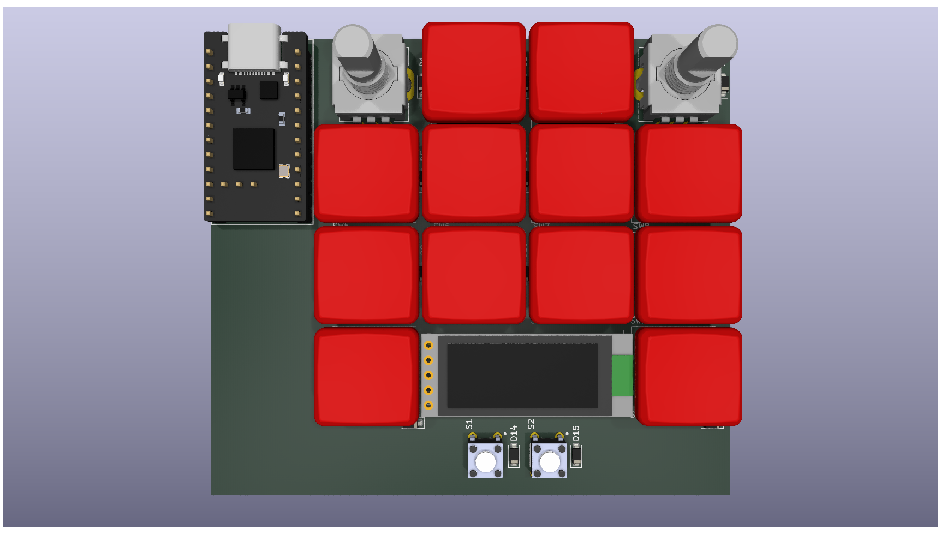
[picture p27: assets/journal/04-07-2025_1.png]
finished pcb layout with keycaps


Changed the right of the schematic for the nice! nano v2 to this which makes more sense (lower rows lower down so the wiring is cleaner):
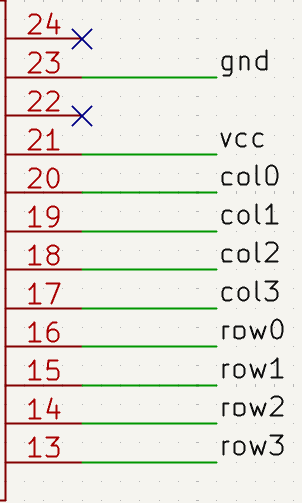
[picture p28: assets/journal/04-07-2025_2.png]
rewired cols and rows on the schematic


FINALLY finished the wiring (no warnings or errors in DRC).

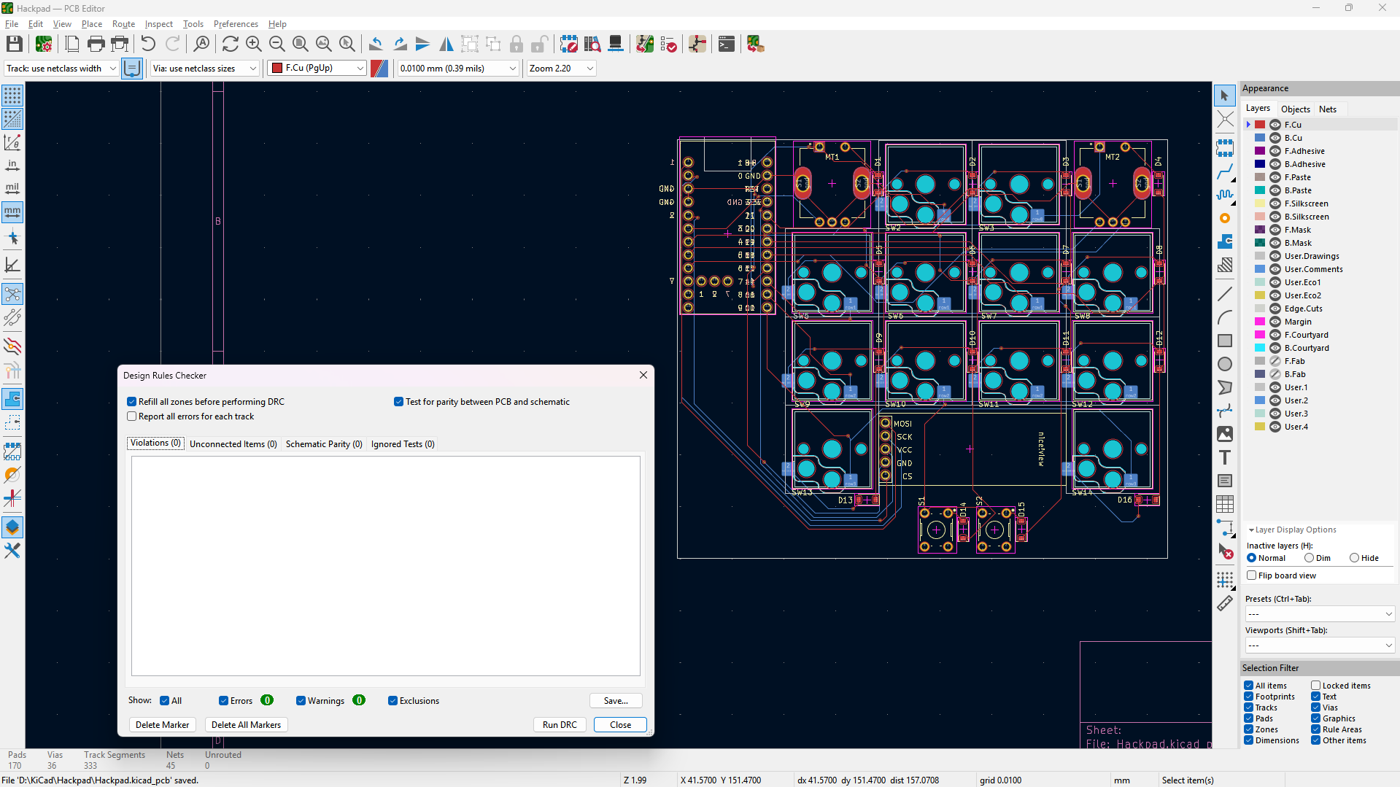
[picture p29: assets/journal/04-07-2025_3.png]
editor view of the wired pcb

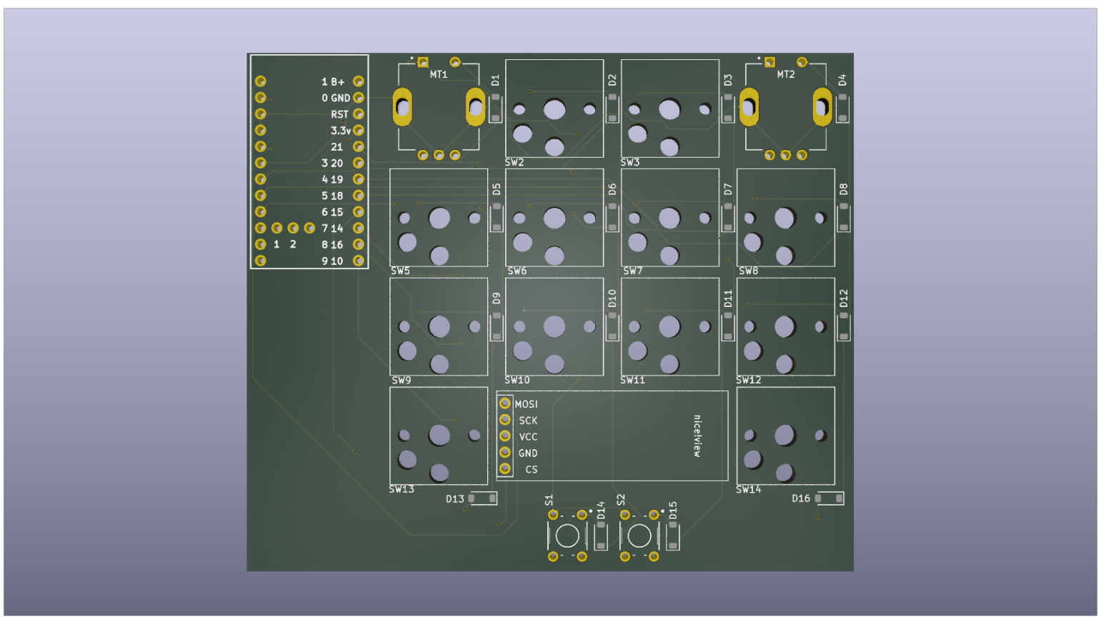
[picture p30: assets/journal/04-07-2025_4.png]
front 3d view of the pcb

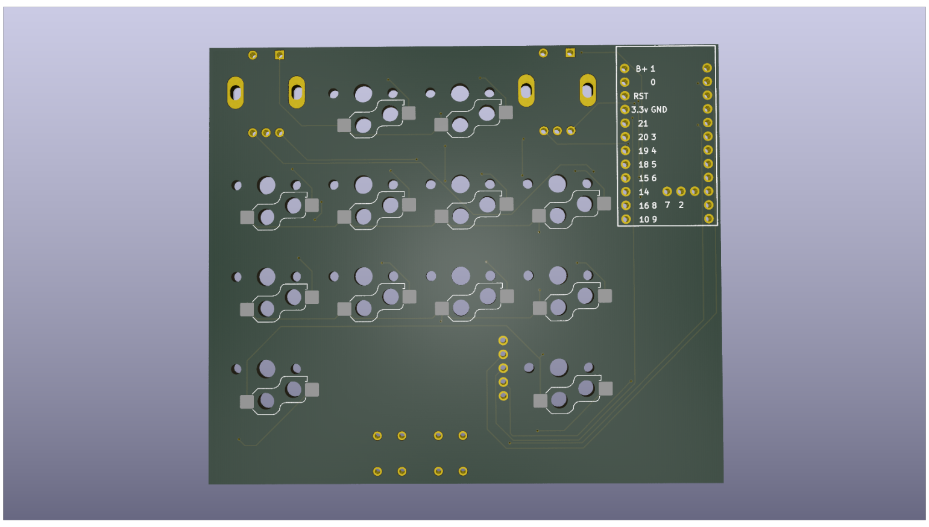
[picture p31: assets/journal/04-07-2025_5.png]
back 3d view of the pcb


> [!NOTE]\
> Total time spent: **5h**

## 05/07/2025

Imported the PCB into Autodesk Fusion 360 and started to design the case (ignore the workspace name, I use Fusion for another competition called F1 in Schools lol)
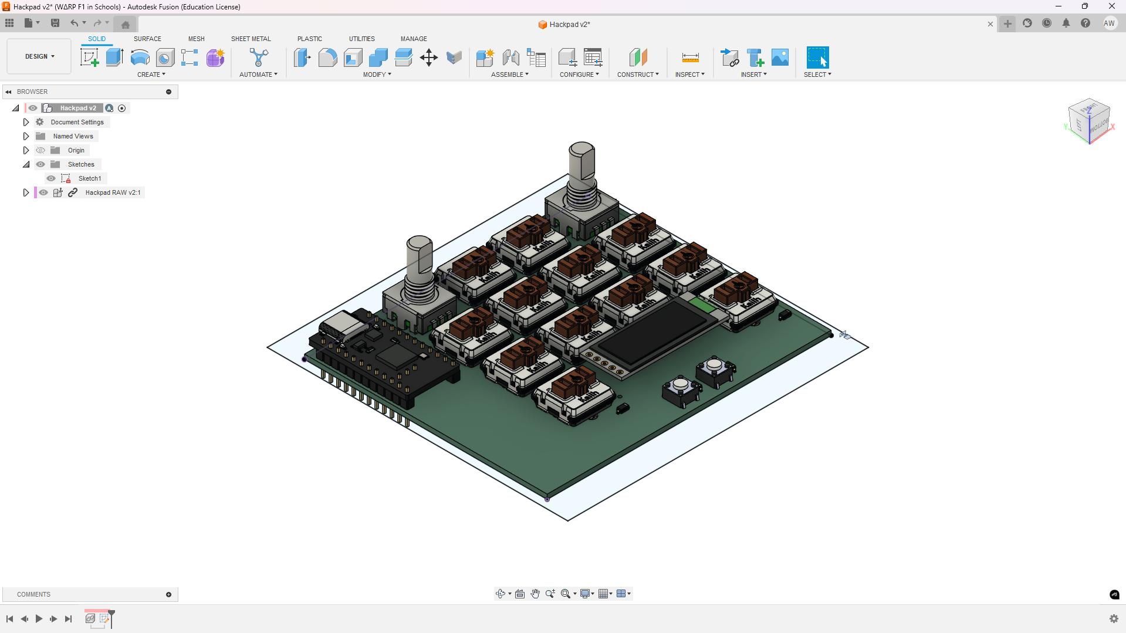
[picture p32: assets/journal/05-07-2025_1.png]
starting work on the case


Made a simple square base of the case:
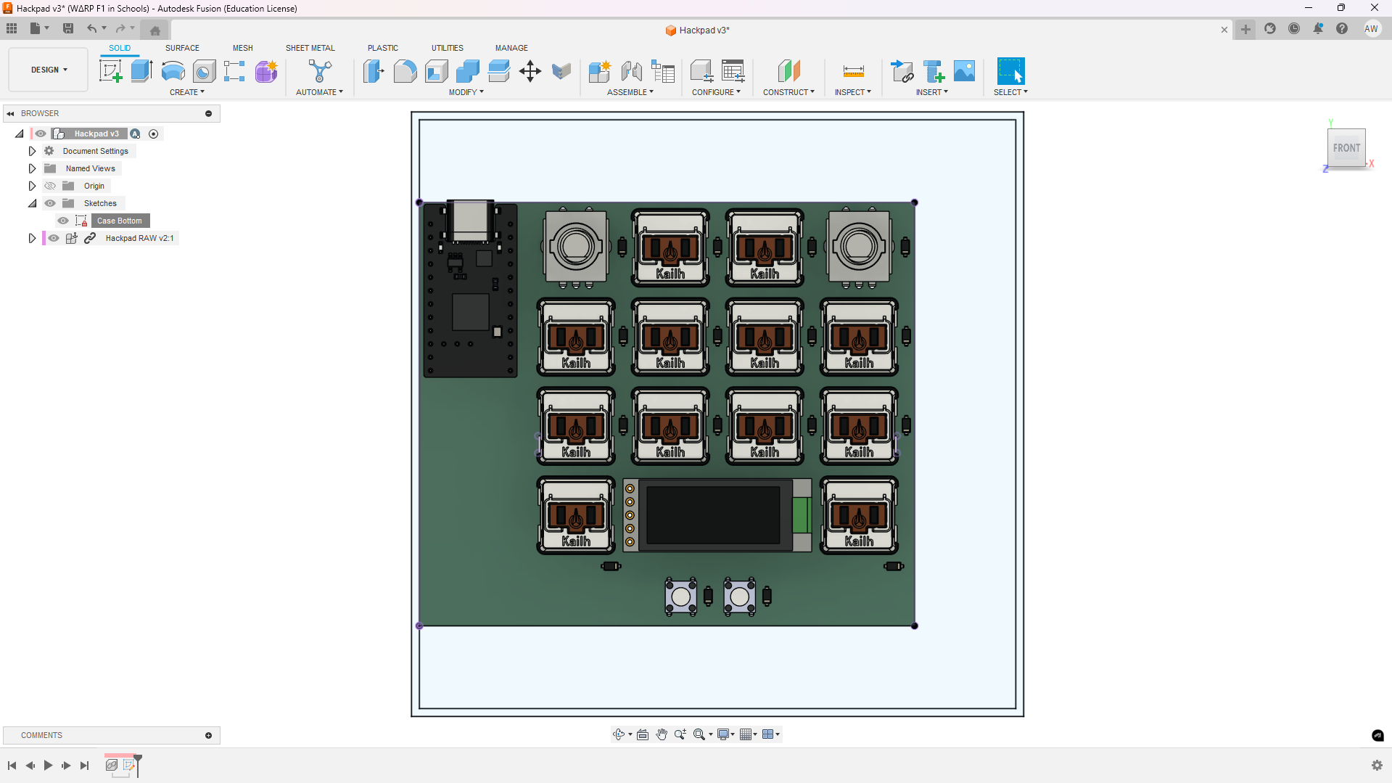
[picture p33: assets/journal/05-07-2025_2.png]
simple case base sketch


> [!NOTE]\
> Total time spent: **1h**

## 06/07/2025

Fixed some of the parameterisation of the case:

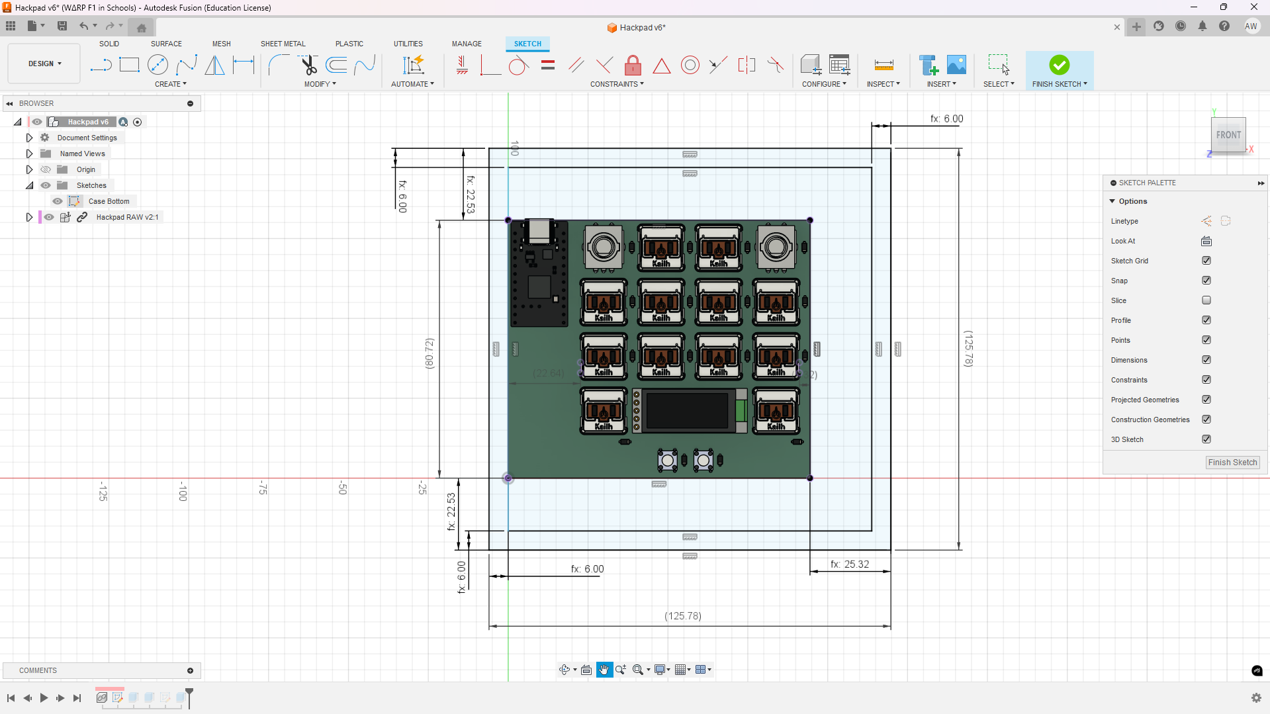
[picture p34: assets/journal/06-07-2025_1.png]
case base walls sketch


Finish plate sketch (dw about the bottom right warning, I'm updating my drivers rn LOL):
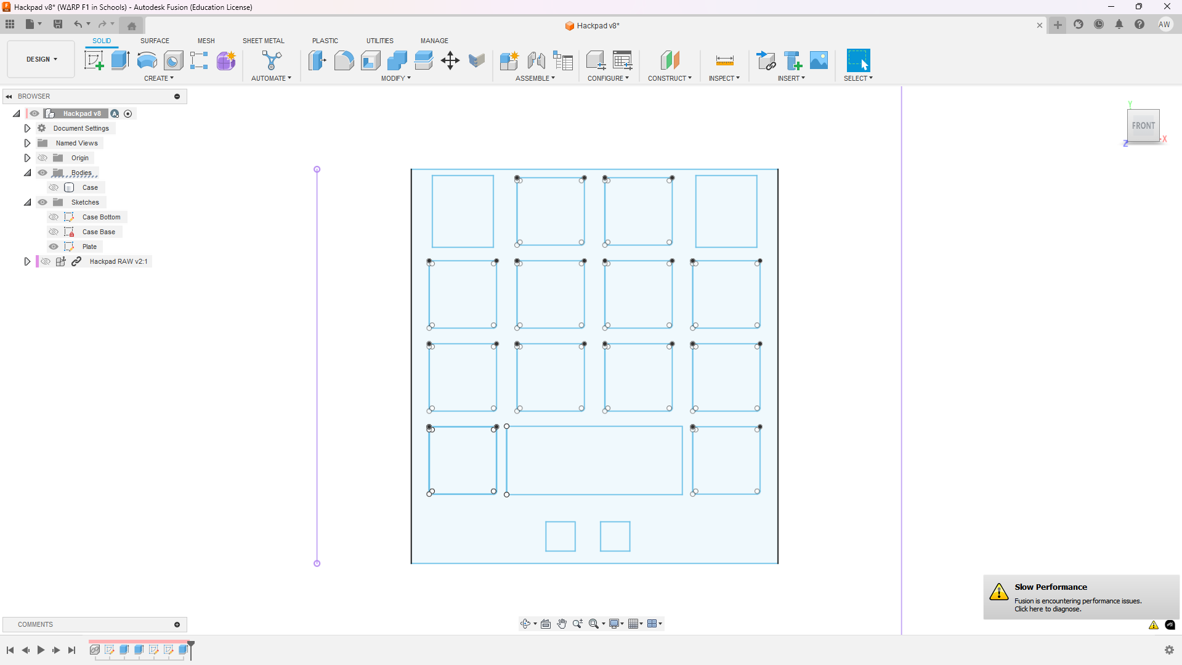
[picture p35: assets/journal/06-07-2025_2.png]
plate sketch


> [!NOTE]\
> Total time spent: **2h**

## 08/07/2025

Moved the microcontroller a bit to the left on the PCB to add more space (had to redo wiring, save me pls).

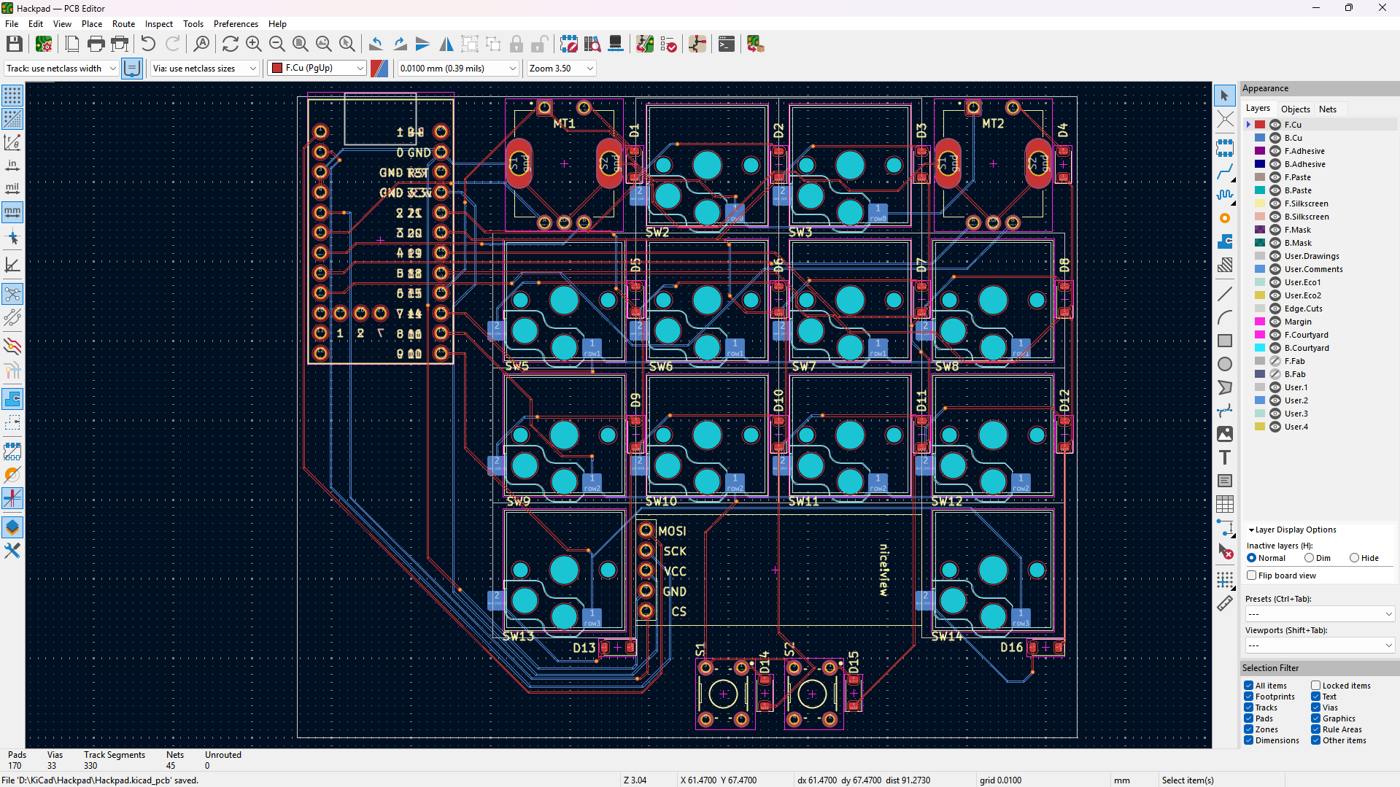
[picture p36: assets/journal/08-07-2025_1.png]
updated pcb with microcontroller a tad more to the left


> [!NOTE]\
> Total time spent: **1h**

## 09/07/2025

Redid design AGAIN lol ;-;.

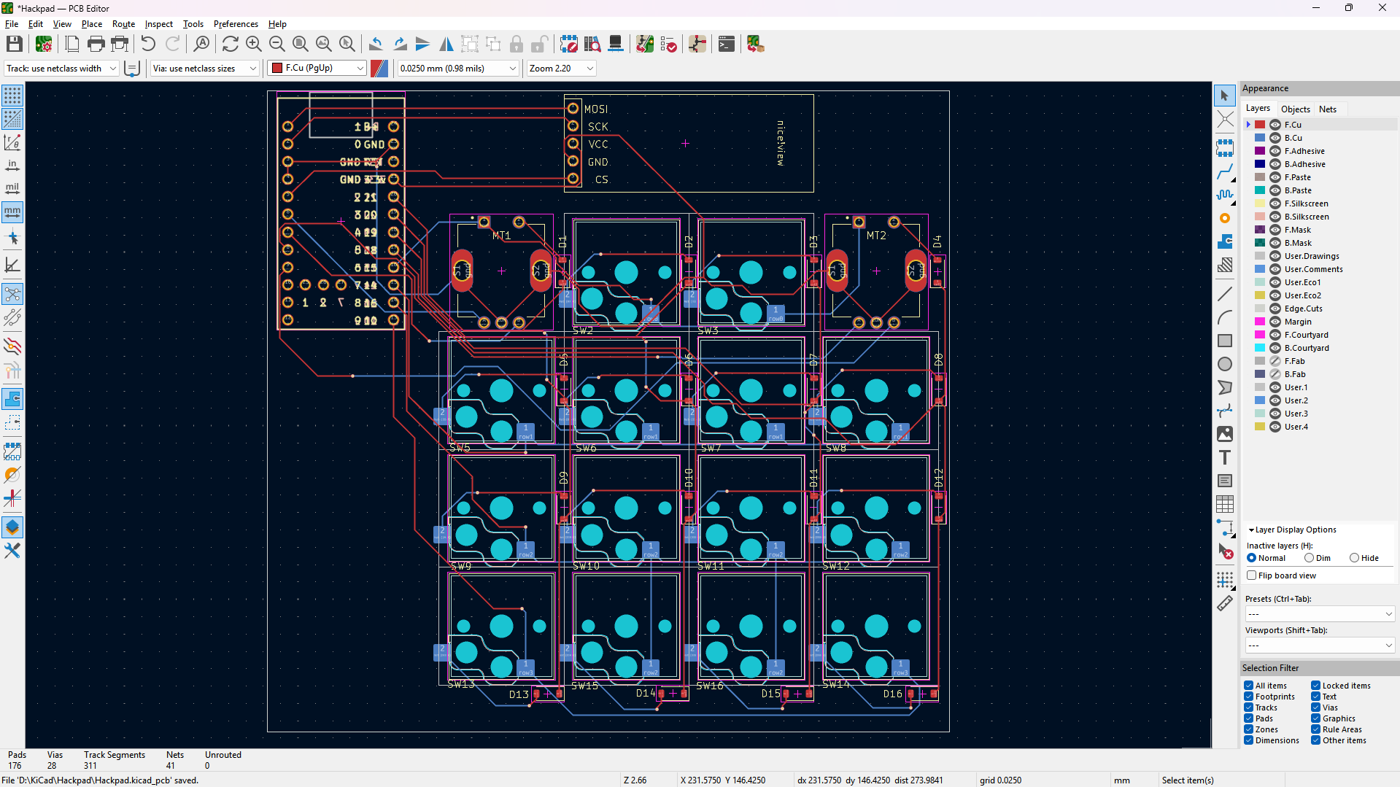
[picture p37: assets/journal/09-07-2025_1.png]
up updated pcb with microcontroller and display on the top now


> [!NOTE]\
> Total time spent: **1h**

## 17/07/2025

I had some work stuff from the 14th - 16th, but the case is finally finished! I'm really sorry for not journalling most of this but it was so tedious and annoying that journalling was just in the back of my mind the whole time. You can see from the amount of sketches and how the version number has incremented the amount of work it has taken ;-; (I have attached proof below though from my time tracker software).

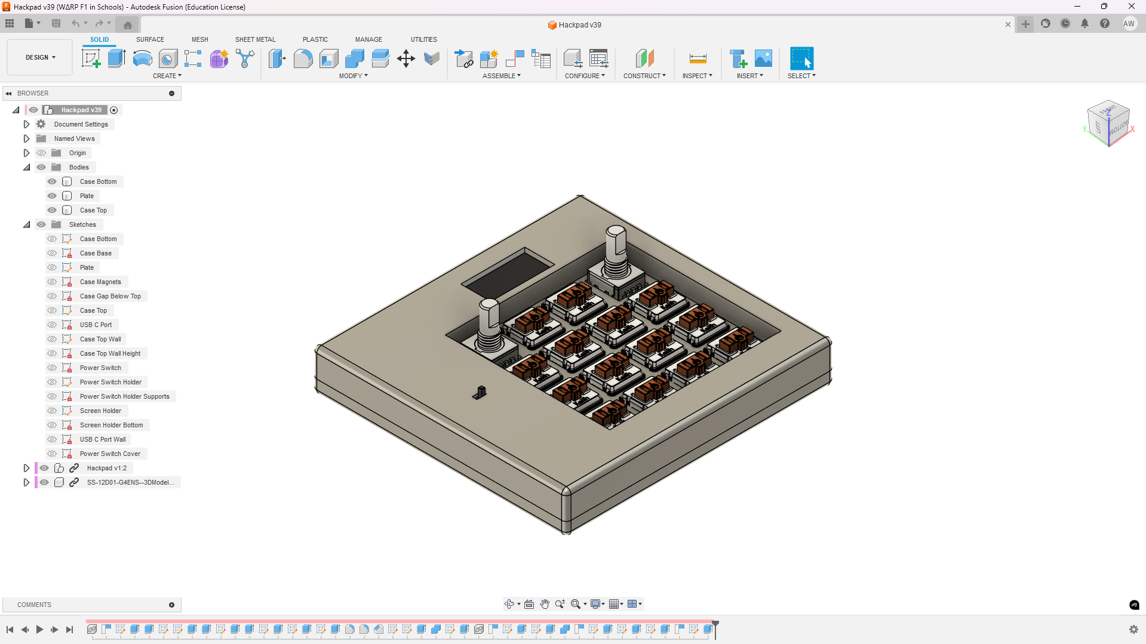
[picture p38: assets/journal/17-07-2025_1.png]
final 3d case model


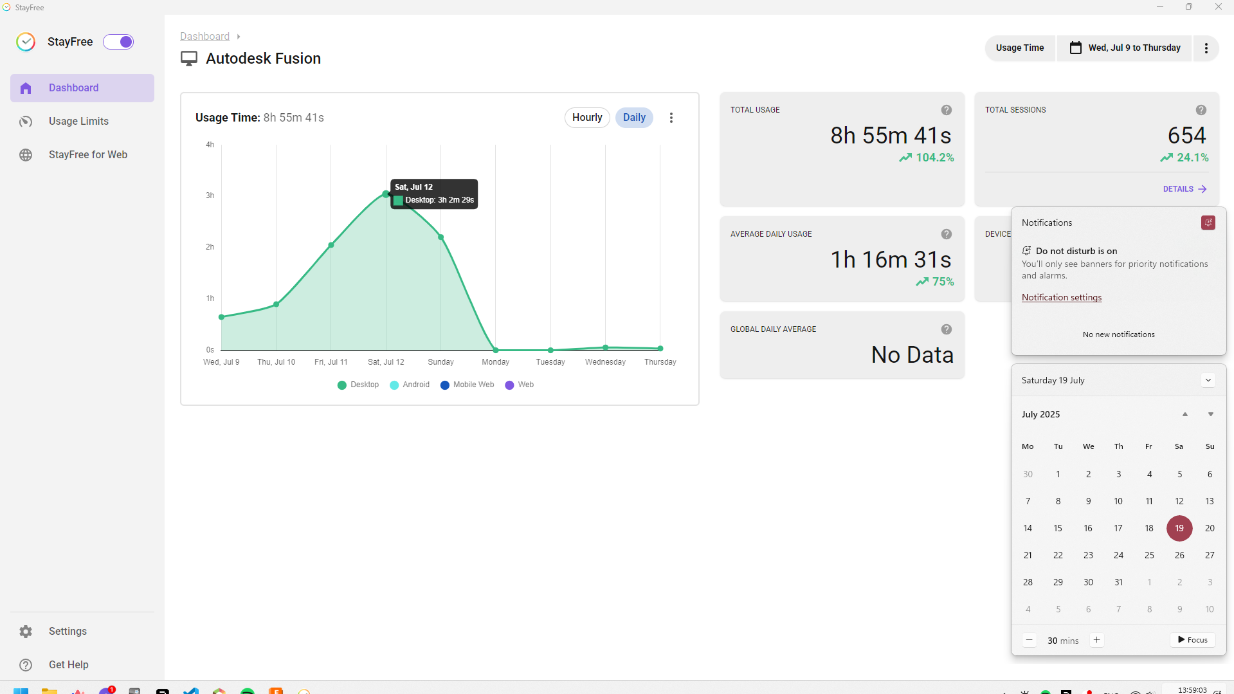
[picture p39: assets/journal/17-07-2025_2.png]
fusion 360 time tracked since last journal in the stayfree app


The parameters tab 😭 (its all for a good cause - flexibility):

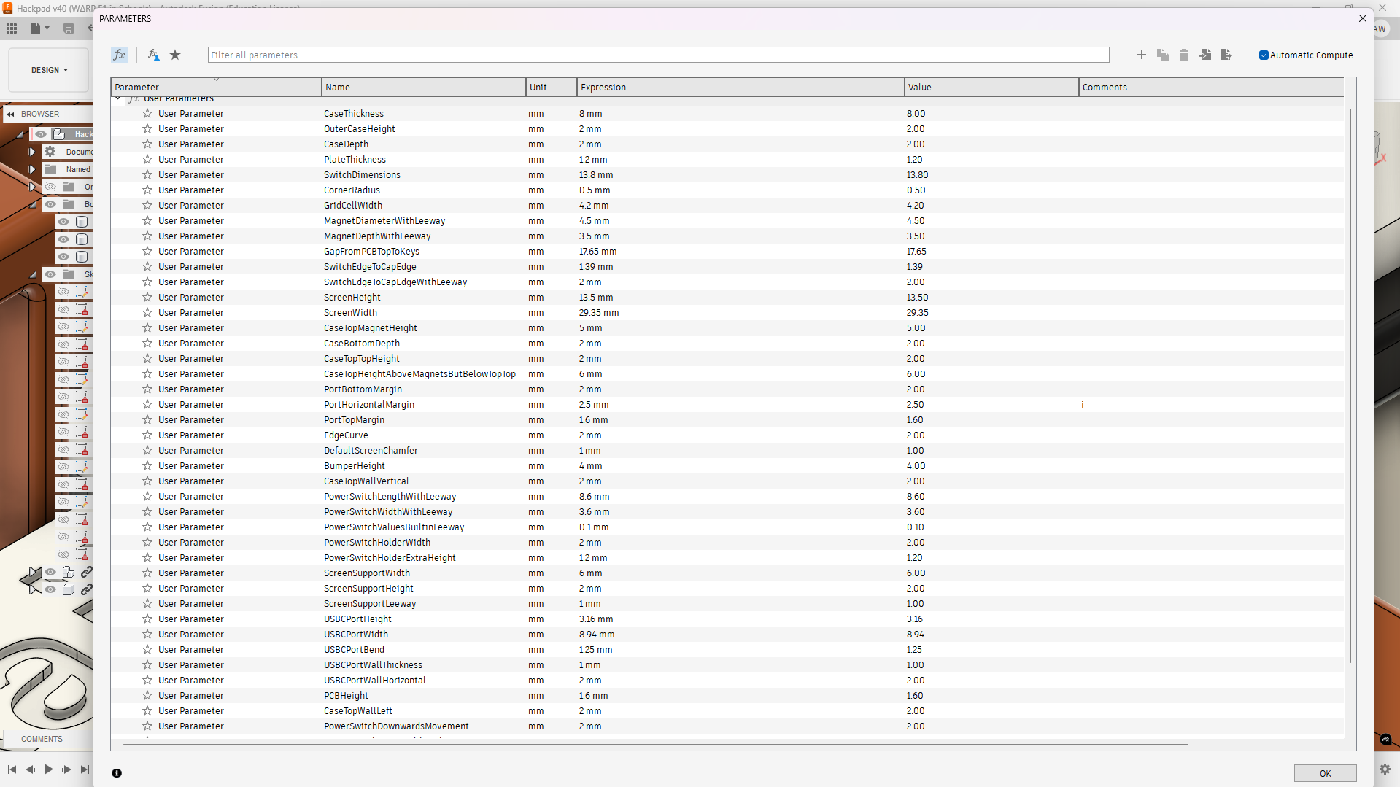
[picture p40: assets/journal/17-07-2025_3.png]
fusion 360 parameters tab


> [!NOTE]\
> Total time spent: **9h**

## 20/07/2025

I JUST SPENT 5 HOURS TRYING TO GET THE DXF SKETCH OF THE PLATE EXPORTED FROM FUSION TO WORK IN KICAD... the whole time it gave the error below - malformed outline. WELL, it turns out even though IT fails to show the 3D model according to the outline, when exported with the Fabrication Toolkit, it works in JLCPCB 😭 (this was such a waste of time just for nothing).





Now I'm going to start writing the README etc.

> [!NOTE]\
> Total time spent: **9h**

## 21/07/2025

Redid the BOM to make it under the $150 limit, had to change some case parameters for that though (thanks to parameterisation it was easy).

> [!NOTE]\
> Total time spent: **6h**

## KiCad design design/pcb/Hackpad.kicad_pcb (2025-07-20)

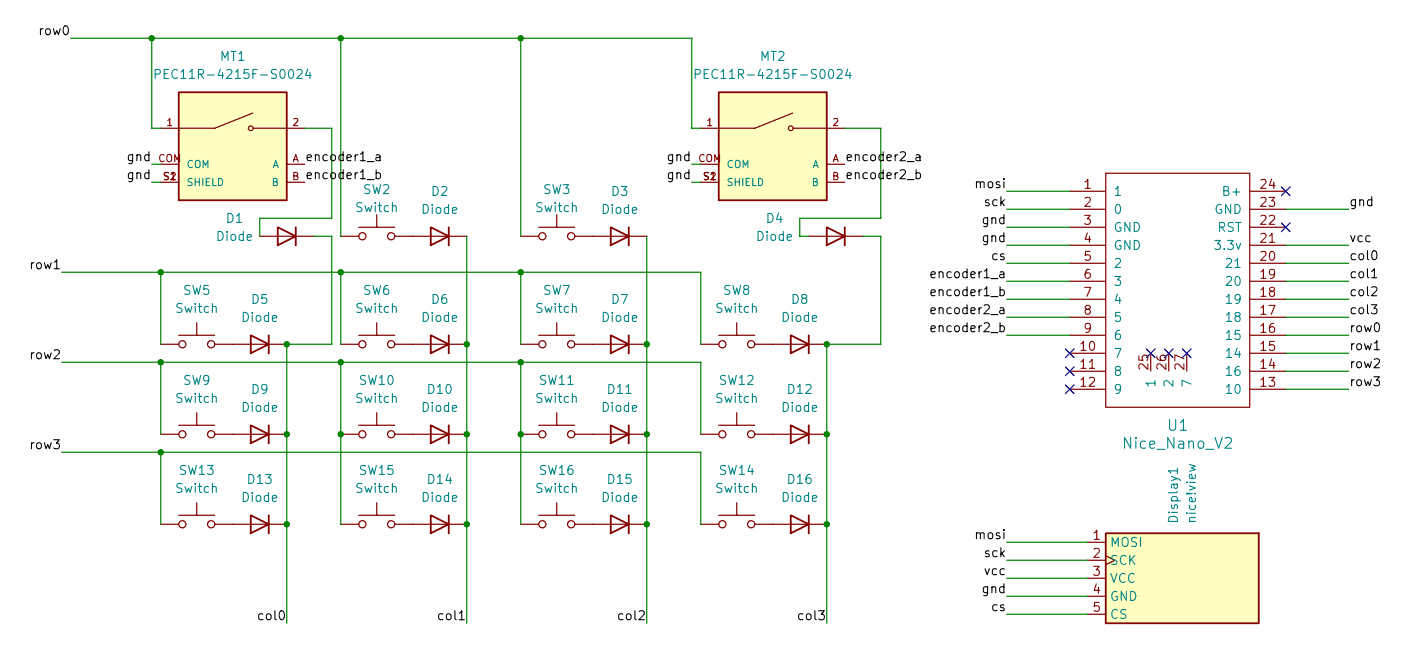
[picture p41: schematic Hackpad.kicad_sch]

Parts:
D1, D2, D3, D4, D5, D6, D7, D8, D9, D10, D11, D12, D13, D14, D15, D16: Diode; D_SOD-123; PARTREV 5
Display1: nice!view; nice_view
MT1, MT2: PEC11R-4215F-S0024; XDCR_PEC11R-4215F-S0024; PARTREV Rev. 09/19
SW2, SW3, SW5, SW6, SW7, SW8, SW9, SW10, SW11, SW12, SW13, SW14, SW15, SW16: Switch; Hotswap_Choc_V1_1.00u
U1: Nice_Nano_V2

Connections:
/col0: D1.1 (K), D5.1 (K), D9.1 (K), D13.1 (K), U1.20 (21)
/col1: D2.1 (K), D6.1 (K), D10.1 (K), D14.1 (K), U1.19 (20)
/col2: D3.1 (K), D7.1 (K), D11.1 (K), D15.1 (K), U1.18 (19)
/col3: D4.1 (K), D8.1 (K), D12.1 (K), D16.1 (K), U1.17 (18)
/cs: Display1.5 (CS), U1.5 (2)
/encoder1_a: MT1.A, U1.6 (3)
/encoder1_b: MT1.B, U1.7 (4)
/encoder2_a: MT2.A, U1.8 (5)
/encoder2_b: MT2.B, U1.9 (6)
/gnd: Display1.4 (GND), MT1.COM, MT1.S1 (SHIELD), MT1.S2 (SHIELD), MT2.COM, MT2.S1 (SHIELD), MT2.S2 (SHIELD), U1.3 (GND), U1.4 (GND), U1.23 (GND)
/mosi: Display1.1 (MOSI), U1.1
/row0: MT1.1, MT2.1, SW2.1, SW3.1, U1.16 (15)
/row1: SW5.1, SW6.1, SW7.1, SW8.1, U1.15 (14)
/row2: SW9.1, SW10.1, SW11.1, SW12.1, SW15.1, SW16.1, U1.14 (16)
/row3: SW13.1, SW14.1, U1.13 (10)
/sck: Display1.2 (SCK), U1.2 (0)
/vcc: Display1.3 (VCC), U1.21 (3.3v)
unnamed: D1.2 (A), MT1.2
unnamed: D2.2 (A), SW2.2
unnamed: D3.2 (A), SW3.2
unnamed: D4.2 (A), MT2.2
unnamed: D5.2 (A), SW5.2
unnamed: D6.2 (A), SW6.2
unnamed: D7.2 (A), SW7.2
unnamed: D8.2 (A), SW8.2
unnamed: D9.2 (A), SW9.2
unnamed: D10.2 (A), SW10.2
unnamed: D11.2 (A), SW11.2
unnamed: D12.2 (A), SW12.2
unnamed: D13.2 (A), SW13.2
unnamed: D14.2 (A), SW15.2
unnamed: D15.2 (A), SW16.2
unnamed: D16.2 (A), SW14.2

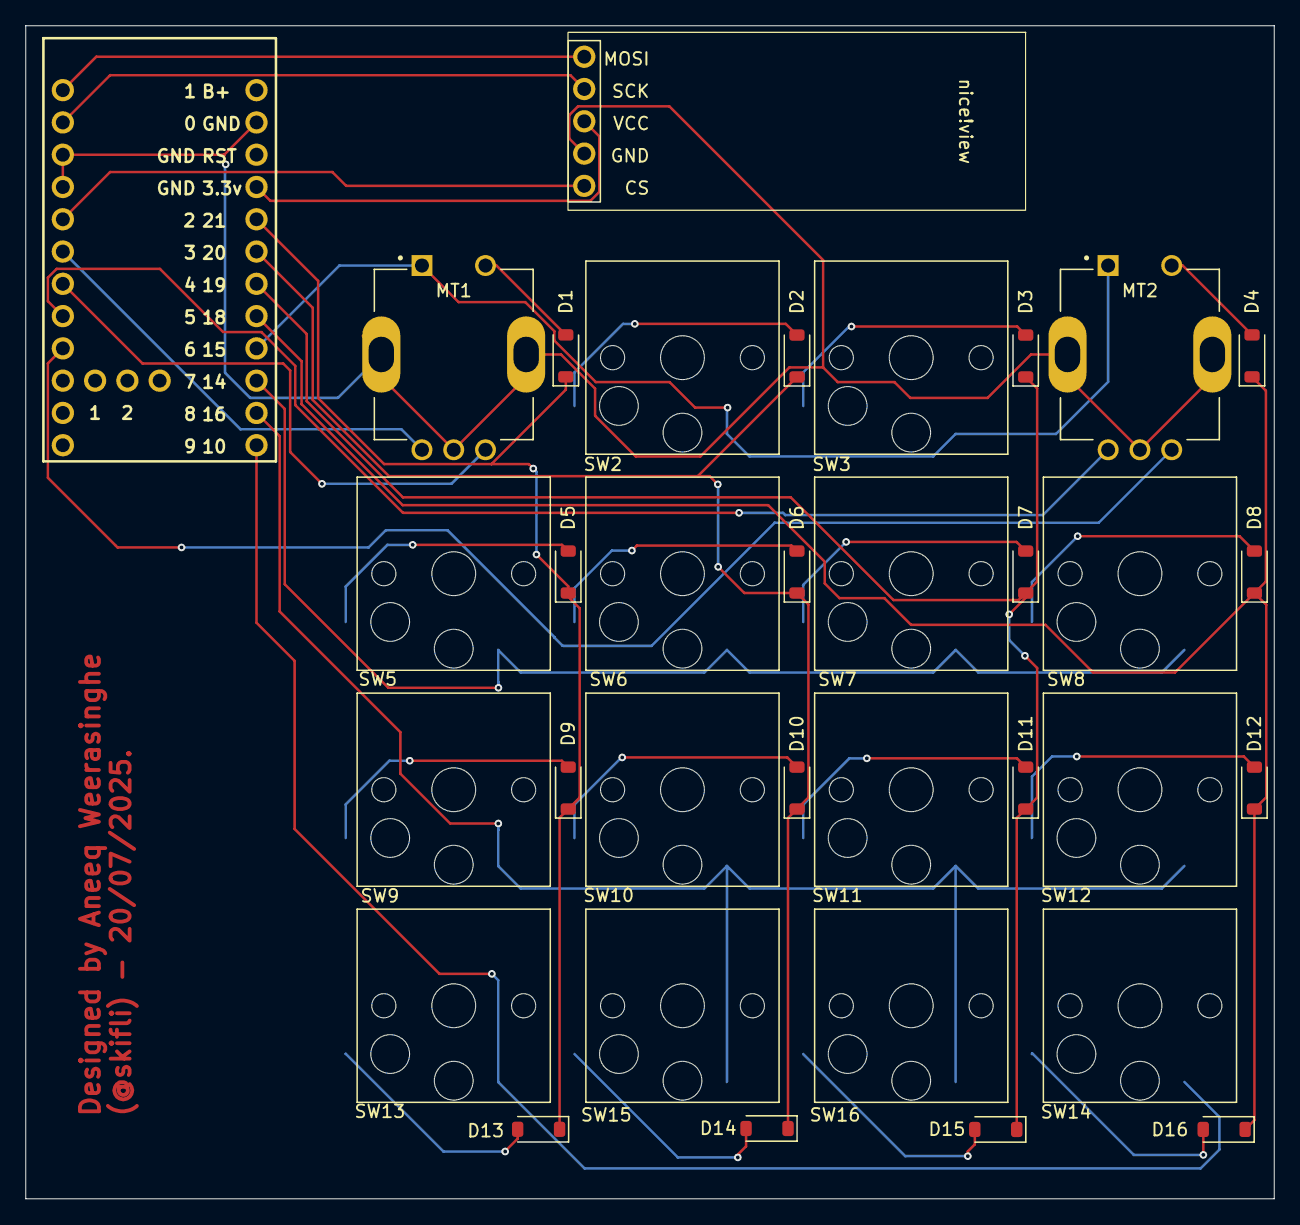
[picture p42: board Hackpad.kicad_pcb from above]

Board: 2 copper layers, 98.2 x 92.3 mm, 34 parts (0 on the bottom side), 33 nets.

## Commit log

2025-07-20 feat: add pcb images
    [Hackpad.kicad_pcb, Hackpad.kicad_sch, case_bottom.step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]
2025-07-20 feat: add case views + BOM
    [bom.csv, designators.csv, positions.csv]
2025-07-20 fix: csv format?
    [bom.csv]
2025-07-20 feat: add bom, update `README.md`
    [bom.csv, case_bottom.step, case_top.step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]
2025-07-20 fix: forgot to update total in `bom.csv`
    [bom.csv]
2025-07-20 feat: update BOM in `README.md`
2025-07-21 feat: add bom in `README.md`
2025-07-21 feat: update `bom.csv` to be way cheaper
    [bom.csv]
2025-07-21 feat: update `README.md`
    [bom.csv]
2025-07-21 feat: add section about BOM price decrease
2025-07-21 fix: bom in `README.md`
2025-07-21 fix: tables in `README.md` BOM
    [bom.csv]
2025-07-21 fix: add jlcpcb pricing
    [bom.csv]
2025-07-21 fix: case for 5mm bumper feet
    [case_bottom.step, case_top.step]
2025-07-21 fix: add jlcpcb price to `README.md` BOM
2025-07-24 feat: reduce BOM price even more!!!
    [bom.csv]
